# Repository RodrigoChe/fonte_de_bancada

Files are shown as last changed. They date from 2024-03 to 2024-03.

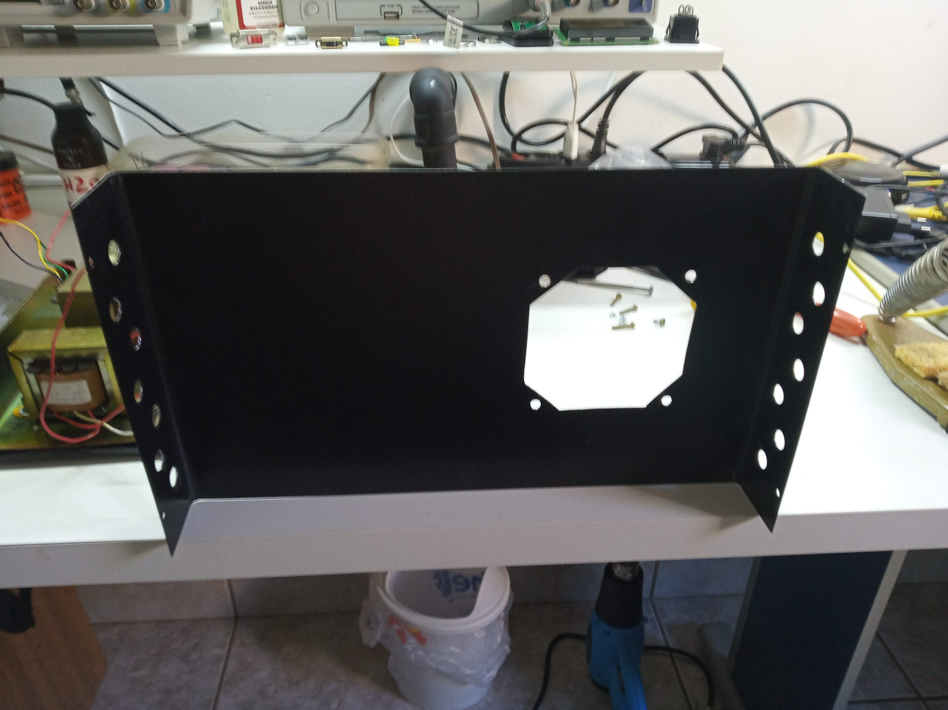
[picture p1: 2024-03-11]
prints_fotos_videos/IMG_20231228_160410.jpg

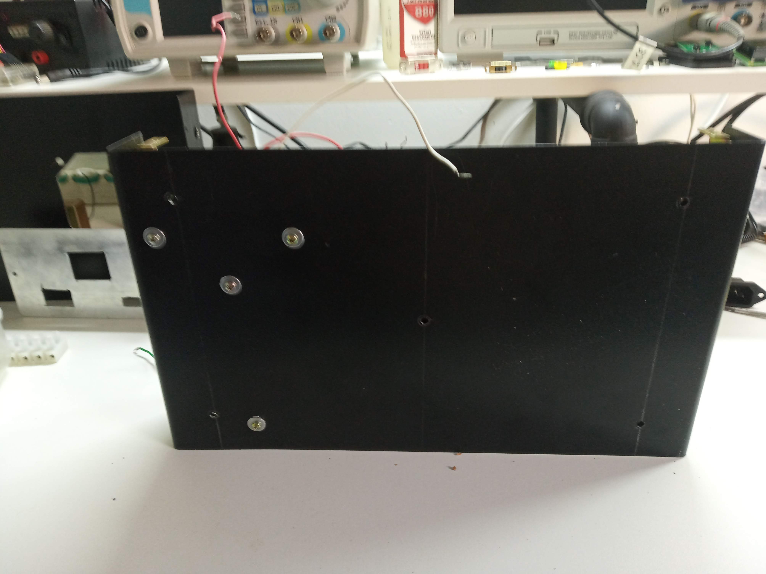
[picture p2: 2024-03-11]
prints_fotos_videos/IMG_20231228_160339.jpg

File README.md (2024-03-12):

# Fonte de bancada 
## Projeto de fonte de bancada ajustável de 1,2V até 30V com corrente de carga contínua de 2A e fonte fixa de 12V com corrente de carga de até 1A.

## Introdução
Este projeto de fonte de bancada handmade tem o objetivo de ser uma opção de baixo custo e boa qualidade para bancada de hobbystas em eletrônica. Foi insparado no projeto de fonte de bancada presente na Revista Mecatrônica Fácil nº 20 de Janeiro/Fevereiro de 2005, com o nome "Fonte para bancada FMF-2" de autoria de Marcio José Soares o Arne, seu projeto original pode ser encontrado [aqui](https://www.arnerobotics.com.br/eletronica/Fonte_bancada_2.htm).
Para o desenvolvimento desse projeto hobbysta foram utilizados:
- Proteus 8.9
- SolidWorks 2019
- Altium 20.0.13
- MikroC 7.2.0

Todas os softwares utilizados com verões trial que possuem limitações de tamanho de placas, número de layers, tamanho de código etc.
Por razões de nostalgia todas as placas foram confecionadas com métodos manuais.
Devido a essas motivações as placas possuem apenas face simples.
A opção por valores de compoenetes e/ou uso de determinado dispisitivo se deve única e exclusivamente a razão de ser  o que havia disponível no momento, a maioria do que foi usado ou já existia na bancada ou foi retirado de eletrônicos velhos. Sinta-se a vontade para modificar quaisqer que sejam os dispositivos e técncias aplicadas. 

## Histórico

Quando era estudante, acho que o ano era 2007, precisava de uma fonte de bancada de baixo ruído para poder realizar meus experimentos com eletrônica e microcontroladores. Foi então que tive acesso a esse artigo da revista Mecatrônica fácil. Na internet na época não tinha encontrado projetos simples que atendessem minha demanda e o baixo conhecimento do idioma inglês dificultava ainda mais rs. 
Dito isso, montei  primeira a versão usando uma carcaça de fonte ATX e alguns componentes que já estavam naquela fonte queimada que encotrei num cemitério de eletrônicos, como conector de rede AC, chave H-H, e mais uns cacarecos. Usei essa montagem por alguns anos até que me mudei de cidade e a fonte ficou abandonada na minha casa antiga. 
Em 2018 resolvi retomar e dar um tapa na minha velha companheira, refiz os esquemáticos e layout e na prensa térmica refiz a placa. Nessa época, aproveitei e já mandei bala em uma fonte fixa de +12 -12 para usar em circuitos com ampOps.
Fiz mais uma mudança e organizando minhas coisas encontrei display de LDC 16x2 que tinha tirado de equipamentos velhos que foram dispensados no meu trabalho e também um PIC18F1220 de saudosos 8 bits que usava para estudar. Como tinha alguns LM358 e um sensor ACS712 que usei para testar umas coisas e depois ficou parado, resolvi fazer um circuito de monitor, porque não neh?
Nessa altura já estavamos mais ou menos na época da pandemia e em meu horário livre aprovetei pra fazer um curso de Altium online e usei o circuito de monitor como objeto de estudo, ao invés do proposto no curso. 
Ai então, a pandemia acabou, voltamos ao normal e minha fonte ainda estava lá parada e desmontada porque não tava rolando uma brecha pra poder mexer. Quando a brecha surgiu optei pela nostalgia em fazer tudo com minhas proprias mãos literalmente. Bem, não tão literal, para prensar a placa do monitor usei um velho ferro de passar roupa e para usinar a caixa usei uma micro retifica de mão (essa altura eu já possuia uma).
E assim foi, montagem, testes, mais uns ajutes ténicos não planejados rs e voalá.

## Conteúdo do repositório

- Cad_mecanico: neste diretório encontram-se arquivos CAD de partes, montagem e pdf's com as medidas.
- prints_fotos_videos: este diretório contém material gráfico do processo de confecção montagem e etc.
- monitor_fonte: arquivos Altium do circuito monitor de corrente, tensão, temperatura e potência, arquivos Proteus de simulação desse circuito, arquivo MikroC de firmware.
- fontes: pdf's dos circuitos esquemáticos das fontes variável e fixa, o arquivo fonte do projeto em Proteus sumiu entre backup's e mudanças. Quando for localizado subo no repositório.

```shell
.
├── cad_mecanico
│   ├── COMPONENTES
│   │   ├── 10A 250VAC Fuse Holder.SLDASM
│   │   ├── 16x2 LCD Display.SLDPRT
│   │   ├── 80 FanCooler-A.SLDASM
│   │   ├── 80 FanCooler-Fan.sldprt
│   │   ├── 80 FanCooler-Frame.sldprt
│   │   ├── 80FanCooler-Guard.sldprt
│   │   ├── Banana Connector - 4.00mm - Short - Black.SLDPRT
│   │   ├── Banana Connector - 4.00mm - Short - Blue.SLDPRT
│   │   ├── Banana Connector - 4.00mm - Short - Green.SLDPRT
│   │   ├── Banana Connector - 4.00mm - Short - Red.SLDPRT
│   │   ├── Banana Connector - 4.00mm - Short - Yellow.SLDPRT
│   │   ├── Chave HH.SLDPRT
│   │   ├── DIN EN ISO 10511 - M4 - N.sldprt
│   │   ├── DIN EN ISO 7045 - M4 x 35 - Z - 35N.sldprt
│   │   ├── EC11_rotary_encoder_knob.SLDPRT
│   │   ├── Frontal.SLDPRT
│   │   ├── Knob 05 v3.SLDASM
│   │   ├── led holder.SLDPRT
│   │   ├── LED_THT_3D_GREEN.SLDPRT
│   │   ├── LED_THT_3D_RED.SLDPRT
│   │   ├── LED_THT_3D_YELLOW.SLDPRT
│   │   ├── Orelha.SLDPRT
│   │   ├── placa_F_fix.SLDPRT
│   │   ├── placa_F_var.SLDPRT
│   │   ├── reforco Interno.SLDPRT
│   │   ├── sapata.SLDPRT
│   │   ├── Switch.SLDPRT
│   │   ├── Tampa.SLDPRT
│   │   ├── TOMADA FÊMEA.SLDPRT
│   │   ├── trafo 1A.SLDPRT
│   │   └── trafo 3A.SLDPRT
│   ├── DESENHOS
│   │   ├── FONTE_montada_1 - Folha1.pdf
│   │   ├── tampa_frontal_1 - Folha1.pdf
│   │   ├── tampa_frontal_2 - Folha1.pdf
│   │   ├── tampa_inferior - Folha1.pdf
│   │   ├── tampa_superior - Folha1.pdf
│   │   ├── tampa_traseira_1 - Folha1.pdf
│   │   └── tampa_traseira_2 - Folha1.pdf
│   └── MONTAGEM
│       └── FONTE.SLDASM
├── fontes
│   ├── esquematicos_placas
│   │   ├── fonte_simetrica_esquema.pdsprj.pdf
│   │   ├── fonte_simetrica.pdsprj.pdf
│   │   ├── fonte_variavel_esquema.pdsprj.pdf
│   │   └── fonte_variavel.pdsprj.pdf
│   └── simulacao_fontes
│       └── Fonte_V1.pdsprj
├── LICENSE
├── monitor_fonte
│   ├── Firmware
│   │   ├── Device.asm
│   │   ├── Device.c
│   │   ├── Device.c.ini
│   │   ├── Device.cp
│   │   ├── Device.h
│   │   ├── Device.h.ini
│   │   ├── Device.mcl
│   │   ├── firmware_monitor.asm
│   │   ├── firmware_monitor.bmk
│   │   ├── firmware_monitor.brk
│   │   ├── firmware_monitor.c
│   │   ├── firmware_monitor.cfg
│   │   ├── firmware_monitor.c.ini
│   │   ├── firmware_monitor.cof
│   │   ├── firmware_monitor.cp
│   │   ├── firmware_monitor.dbg
│   │   ├── firmware_monitor.dct
│   │   ├── firmware_monitor.dlt
│   │   ├── firmware_monitor.hex
│   │   ├── firmware_monitor.log
│   │   ├── firmware_monitor.lst
│   │   ├── firmware_monitor.lst.ini
│   │   ├── firmware_monitor.mcl
│   │   ├── firmware_monitor.mcppi
│   │   ├── firmware_monitor.mcppi_callertable.txt
│   │   ├── firmware_monitor.user.dic
│   │   └── firmware_monitor.wch
│   ├── PCB_Altium
│   │   └── PCB_INSTRUMENTATION_VSOURCE
│   │       ├── main.SchDoc
│   │       ├── PCB_INST_FONTE.PcbDoc
│   │       ├── PCB_INSTRUMENTATION_VSOURCE.PrjPcb
│   │       ├── __Previews
│   │       │   ├── main.SchDocPreview
│   │       │   ├── Sheet1.SchDocPreview
│   │       │   └── Sheet2.SchDocPreview
│   │       ├── Producao
│   │       │   ├── Geber_Placa.Cam
│   │       │   ├── NC_Drill_Placa.Cam
│   │       │   ├── Schematic Prints 1.pdf
│   │       │   ├── Schematic Prints 2.pdf
│   │       │   ├── Schematic Prints.pdf
│   │       │   └── Thermal_transfer
│   │       │       ├── Mask_Impressao_TermoCAM.pdf
│   │       │       ├── Mask_Print_Term_Transfer.pdf
│   │       │       └── Print_Fab_Home_Thermal.pdf
│   │       ├── Project Outputs for PCB_INSTRUMENTATION_VSOURCE
│   │       │   ├── Design Rule Check - PCB_INST_FONTE.drc
│   │       │   ├── Design Rule Check - PCB_INST_FONTE.html
│   │       │   ├── PCB_INST_FONTE.apr
│   │       │   ├── PCB_INST_FONTE.DRR
│   │       │   ├── PCB_INST_FONTE.EXTREP
│   │       │   ├── PCB_INST_FONTE.GBL
│   │       │   ├── PCB_INST_FONTE.GBO
│   │       │   ├── PCB_INST_FONTE.GBS
│   │       │   ├── PCB_INST_FONTE.GG1
│   │       │   ├── PCB_INST_FONTE.GM1
│   │       │   ├── PCB_INST_FONTE.GM13
│   │       │   ├── PCB_INST_FONTE.GM15
│   │       │   ├── PCB_INST_FONTE.GPB
│   │       │   ├── PCB_INST_FONTE.GPT
│   │       │   ├── PCB_INST_FONTE.GTL
│   │       │   ├── PCB_INST_FONTE.GTO
│   │       │   ├── PCB_INST_FONTE.GTS
│   │       │   ├── PCB_INST_FONTE.LDP
│   │       │   ├── PCB_INST_FONTE-macro.APR_LIB
│   │       │   ├── PCB_INST_FONTE.REP
│   │       │   ├── PCB_INST_FONTE.RUL
│   │       │   ├── PCB_INST_FONTE.TXT
│   │       │   ├── PCB_INSTRUMENTATION_VSOURCE_BOM.xlsx
│   │       │   ├── __Previews
│   │       │   │   └── Design Rule Check - PCB_INST_FONTE.drcPreview
│   │       │   └── Status Report.Txt
│   │       ├── Sheet1.SchDoc
│   │       └── Sheet2.SchDoc
│   └── Simulacao
│       └── simulacao_monitor_fonte.pdsprj
├── prints_fotos_videos
│   ├── cad_vista_monategm_1.png
│   ├── cad_vista_monategm_2.png
│   ├── cad_vista_monategm_3.png
│   ├── cad_vista_monategm_4.png
│   ├── IMG-20220224-WA0000.jpg
│   ├── IMG-20220224-WA0002.jpg
│   ├── IMG-20220224-WA0003.jpg
│   ├── IMG-20220224-WA0004.jpg
│   ├── IMG_20220310_143831.jpg
│   ├── IMG_20220310_143843.jpg
│   ├── IMG_20220315_130520.jpg
│   ├── IMG_20220315_130540.jpg
│   ├── IMG_20220921_200834.jpg
│   ├── IMG_20220921_201358.jpg
│   ├── IMG-20230129-WA0006.jpeg
│   ├── IMG_20231120_121806.jpg
│   ├── IMG_20231228_160329.jpg
│   ├── IMG_20231228_160339.jpg
│   ├── IMG_20231228_160359.jpg
│   ├── IMG_20231228_160410.jpg
│   ├── IMG_20231229_150956.jpg
│   ├── IMG_20240110_225814.jpg
│   ├── IMG_20240113_172508.jpg
│   ├── IMG_20240113_201511.jpg
│   ├── IMG_20240210_154214.jpg
│   ├── IMG-20240229-WA0002.jpeg
│   ├── IMG-20240301-WA0006.jpeg
│   ├── IMG-20240301-WA0008.jpeg
│   ├── IMG-20240301-WA0012.jpeg
│   ├── simula.PNG
│   └── VID-20240301-WA0018.mp4
└── README.md
```

## Observações

Circuito de fonte simétrica fixa.
Este circuito é extremamente simples sendo composto por um retificador em ponte completa com trasnformador de 15+15 @1A, diodos 1N4004, filtro capacitivo e reguladores LM7812 e LM7912. Seu layout pode ser bastante reduzido, sugiro colocar bons dissipadores de calor (reguladores lineares dissipam muito calor). Os leds de sinalização são totalmente dispensáveis, caso opte por eles seria interessante um trafo maior para termos um pouco mais de 15V na entrada do regulador, pois a tensão dropOut necessária para regulação fica em torno de uns 3V. 

Circuito de fonte ajustável.
Este circuito também é simples sendo composto por um transformador abaixador de 15+15V @3A, ponte retificadora com 4 diodos 1N5408, filtro capacitivo e regulador LM350. O layout que usei foi inspirado no da revista, mas o LM350 sugiro monta-lo separado com um dissipador de calor grande para poder fornecer os 3A sem acionar o circuito de proteção térmica. Com isso o layout fica bem reduzido também.  Outa sugestão é utilizar outro encapsulamento e colocar os diodos de proteção conforme o datasheet do componente encontrado [aqui](https://www.ti.com/lit/ds/symlink/lm350-n.pdf?ts=1710238548220&ref_url=https%253A%252F%252Fwww.mouser.fr%252F). No esquemático deste projeto utilizei o capacitor de redução de ripple, conforme o datasheet isso tende a melhorar a resposta para ruídos de entrada sob carga. 

Circuito monitor
Bem este circuito já não é tão simples, pois possui um mirocontrolador PIC18F1220 que precisa de um firmware para funcionar. Sua finalidade é medir a tensão, corrente, temperatura, potência de saída da fonte ajustável e medir se a tensão fixa esta dentro de limites aceitáveis (tinha espaço no LCD). Apresentando a medida em um display de LCD 16x2 vias. 
Para medir tensão são usados divisores de tensão na entreda de LM358's datasheet [aqui](https://www.ti.com/lit/ds/symlink/lm358.pdf?ts=1710219620944) como buffers de tensão que servem pra isolar e proteger o microcontrolador, também foram usados diodo zener de proteção e um filtro RC. Para a medição de tempratura foi usado o famigerado LM35  [datasheet](https://www.ti.com/lit/ds/symlink/lm35.pdf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), foi fixado perto do LM350 no dissipador de calor usando adesivo térmico homemade vulgo pasta térmica com adesivo epóxi. Para medição de corrente foi usado um módulo do sensor ACS712 datasheet [aqui](https://www.sparkfun.com/datasheets/BreakoutBoards/0712.pdf), esse dispositivo apenas foi usado porque tinha disponível. Ele é bem ruim para baixas correntes dc. Ficando mais como um alarme do que uma medida confiável. Sugiro a substituição desse sensor ou mesmo projetar algo com compnentes discretos. 
Para o firmware do microcontrolador quiz usar o ambiente que usava [Na aurora da minha vida!](https://poemasdomundo.wordpress.com/2006/06/14/meus-oito-anos/) lá no tempo do curso técnico (o Arduino não era muito conhecido ainda...). Então foi na base do MikroC mesmo que tem umas libs que facilitam trabalhar com display. Hoje em dia compensa muito mais usar as ferramentas da Microchip, Mplab, Harmony e etc. 
Por último, sugiro usar um circuitinho de referência externa de tensão para o ADC, mesmo em outros microocntroladores. Neste projeto foi usado o TL431 datasheet [aqui](https://www.ti.com/lit/ds/symlink/tl431.pdf?ts=1710220283391&ref_url=https%253A%252F%252Fwww.mouser.com%252F).
Sinceramente, da pra dispensar esse circuito com traqnuilidade, caso queira economizar dinheiro e mão de obra pode optar por um monitor pronto com voltimetro e amperimetro Dc (desses que vende barato em sites amarelos da rede mundial de computadores) [como exemplo](https://www.4hobby.com.br/produto/voltimetro-amperimetro-digital-dc-100v-10a-para-painel.html).

Montagem
Para montagem foi utilizado uma caixa metálica de  300x180x80 mm tem algumas opções na internet por [ai](https://www.soldafria.com.br/componentes-eletronicos/caixa/caixa-de-ferro) (de longe a caixa foi o componente mais caro). Outra opção pode ser caixas padrão plásticas, reaproveitar alguma coisa, fazer de madeira, opções existem e a imaginação é o limite. Recomendo fortemente o uso de ventilação forçada a famosa ventoinha e o uso de bons bornes e chaves de qualidade.
Um vídeo da fonte alimentando uam lampada DC e um circuito amplificador pode ser visto [neste link](https://www.youtube.com/shorts/OysOYpLijRs).

## License

MIT

**Free Software, Hell Yeah!**

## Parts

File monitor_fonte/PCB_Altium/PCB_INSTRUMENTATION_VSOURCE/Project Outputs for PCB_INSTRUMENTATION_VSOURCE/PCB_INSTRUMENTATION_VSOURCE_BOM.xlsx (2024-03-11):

Comment | Description | Designator | Footprint | LibRef | Quantity | Supplier 1 | Supplier Part Number 1
100nF | Capacitor | C1, C3, C5, C7, C11 | RAD-0.2 | C | 5
2200 uF @25V | Polarized Capacitor | C2 | CAPPR5-13x21 | CP | 1
330nF | Capacitor | C4, C6 | RAD-0.2 | C | 2
22pF | Capacitor | C8, C9, C10 | RAD-0.2 | C | 3
100n | Capacitor | C12, C13, C14, C15, C16, C17, C18 | RAD-0.2 | C | 7
1N4007 | Diode | D1, D2, D3, D4 | DIODE-1N400X | D | 4
1N4007 | 1 Amp General Purpose Rectifier | D5 | DO-41 | Diode 1N4007 | 1
1N4733 | Zener Diode | D6, D7, D8 | DIODE-SIGNAL | D Zener | 3
AC(IN) | Header, 3-Pin | P1 | HDR1X3 | Header 3 | 1
LCD 16x2 | Header, 10-Pin | P2 | HDR1X10 | Header 10 | 1
FAN | Header, 3-Pin | P3 | HDR1X3 | Header 3 | 1
V var | Header, 3-Pin | P4 | HDR1X3 | Header 3 | 1
V fixed | Header, 3-Pin | P5 | HDR1X3 | Header 3 | 1
ACS712 | Header, 3-Pin | P6 | HDR1X3 | Header 3 | 1
4k7 | Resistor | R1 | AXIAL-0.4 | R | 1
150r | Resistor | R2 | AXIAL-0.4 | R | 1
12k | Resistor | R3, R7 | AXIAL-0.4 | R | 2
24k | Potentiometer | R4 | VR1 | R Pot | 1
6k8 | Resistor | R5 | AXIAL-0.4 | R | 1
100k | Potentiometer | R6 | VR1 | R Pot | 1
100k | Resistor | R8 | AXIAL-0.4 | R | 1
1k | Resistor | R9, R10, R11 | AXIAL-0.4 | R | 3
100 | Resistor | R12 | AXIAL-0.4 | R | 1
PIC18F1220-I/P | High Performance, Enhanced Flash Microcontroller with 10-Bit A/D and nanoWatt Technology, 4K Flash, 18-Pin PDIP, Industrial Temperature | U1 | PDIP300-P18 | PIC18F1220-I/P | 1 | Digi-Key | PIC18F1220-I/P-ND
LM7812 | Series 3-Terminal Positive Regulators, 3-pin TO-220 | U2 | T03B | LM7808CT | 1 | Farnell | 9490248
LM7805 | Series 3-Terminal Positive Regulators, 3-pin TO-220 | U3 | T03B | LM7808CT | 1 | Farnell | 9490248
TL431ACLP | Adjustable Precision Shunt Regulator | U4 | LP03 | TL431ACLP | 1
LM358AJG | Dual Operational Amplifier | U5, U6 | JG008 | LM358AJG | 2
LM35CAZ | Precision Centigrade Temperature Sensor, 3-pin TO-92 | U7 | Z03A | LM35CAZ | 1 | Farnell | 9494529
10MHz | Crystal Oscillator | Y1 | CRYSTAL-HC49S | XTAL | 1

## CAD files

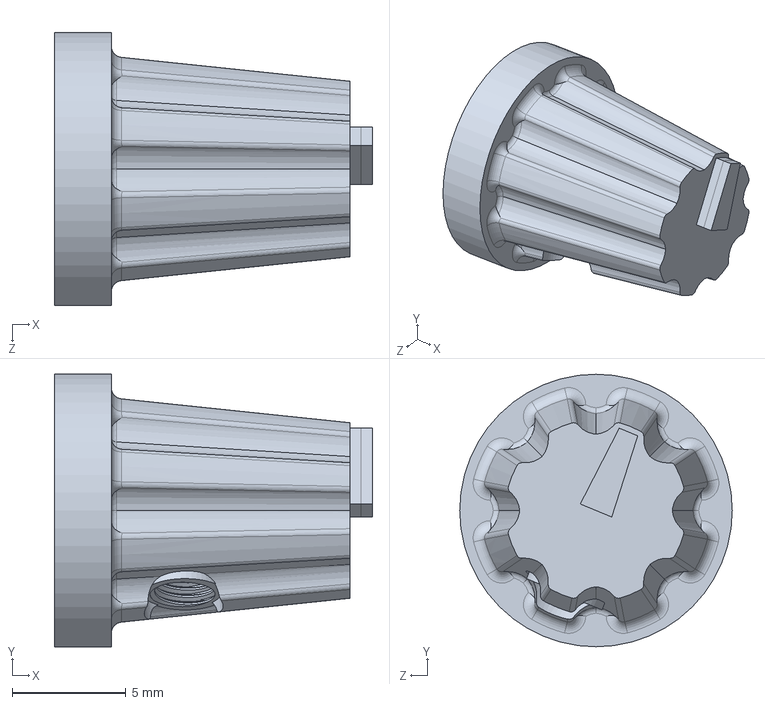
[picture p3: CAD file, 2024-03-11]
cad_mecanico/COMPONENTES/Knob 05 v3.SLDASM
14.0 x 12.0 x 12.0 mm

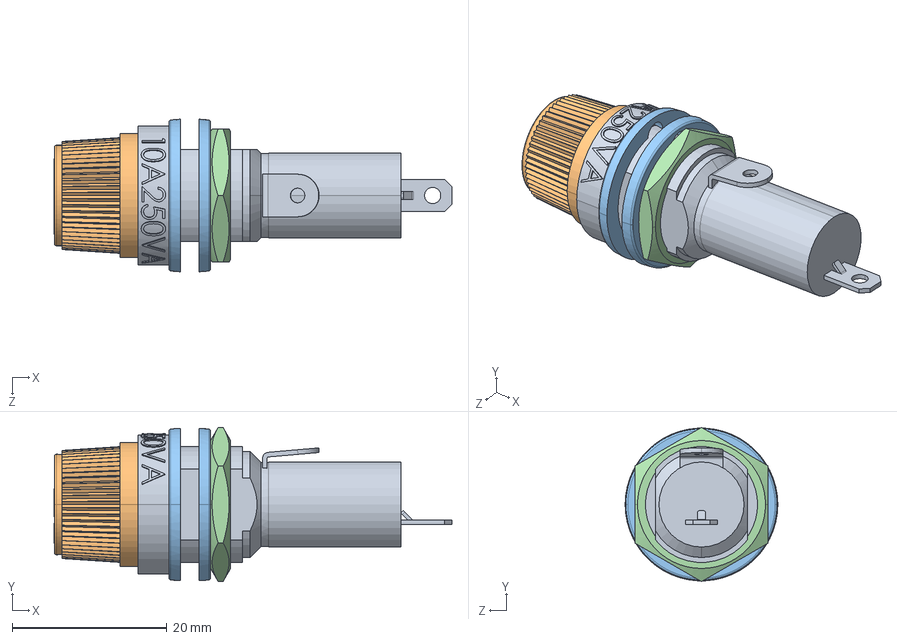
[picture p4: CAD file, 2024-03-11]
cad_mecanico/COMPONENTES/10A 250VAC Fuse Holder.SLDASM
51.5 x 19.9 x 19.8 mm
SF372 - Body.STEP
SF372 - Cap.STEP
SF372 - Nylon Washer.STEP x 2
SF372 - Nut.STEP

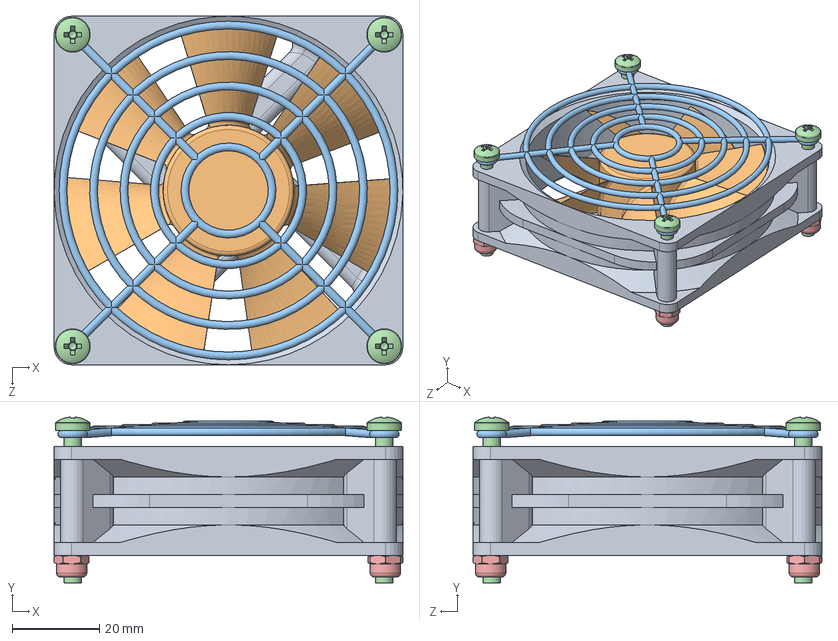
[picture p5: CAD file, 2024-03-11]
cad_mecanico/COMPONENTES/80 FanCooler-A.SLDASM
80.1 x 38.0 x 80.1 mm
80 FanCooler-Frame
80 FanCooler-Fan
80FanCooler-Guard
DIN EN ISO 7045 - M4 x 35 - Z - 35N x 4
DIN EN ISO 10511 - M4 - N x 4

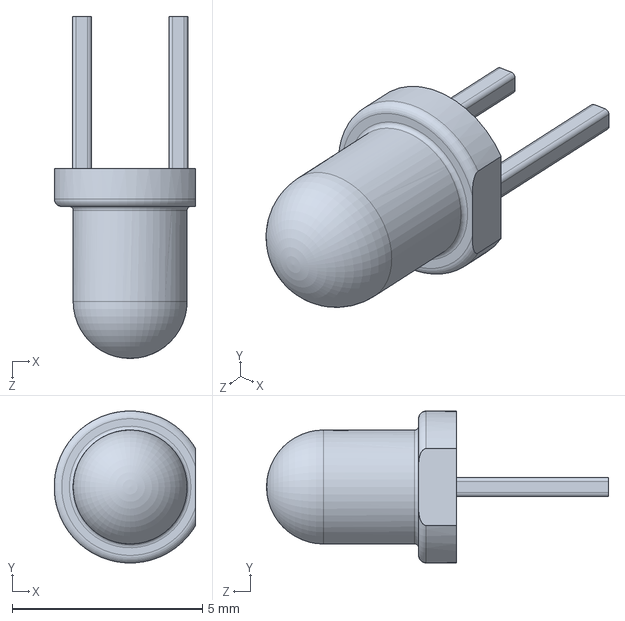
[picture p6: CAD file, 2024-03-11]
cad_mecanico/COMPONENTES/LED_THT_3D_GREEN.SLDPRT
3.72 x 4.00 x 9.00 mm

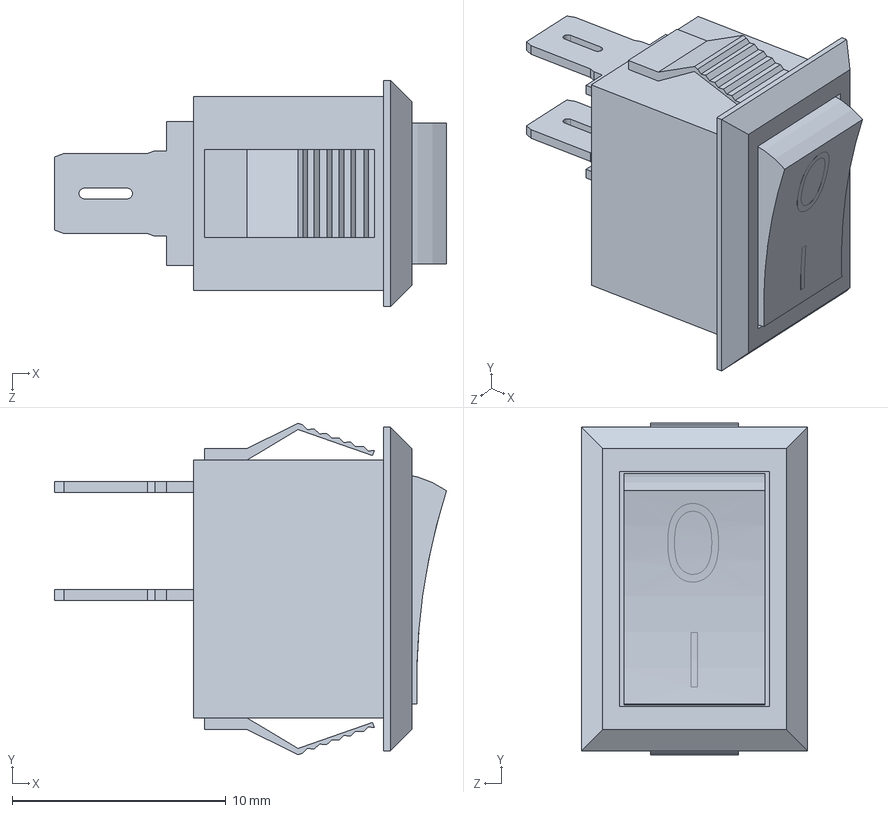
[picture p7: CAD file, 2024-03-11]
cad_mecanico/COMPONENTES/Switch.SLDPRT
18.3 x 15.5 x 10.6 mm

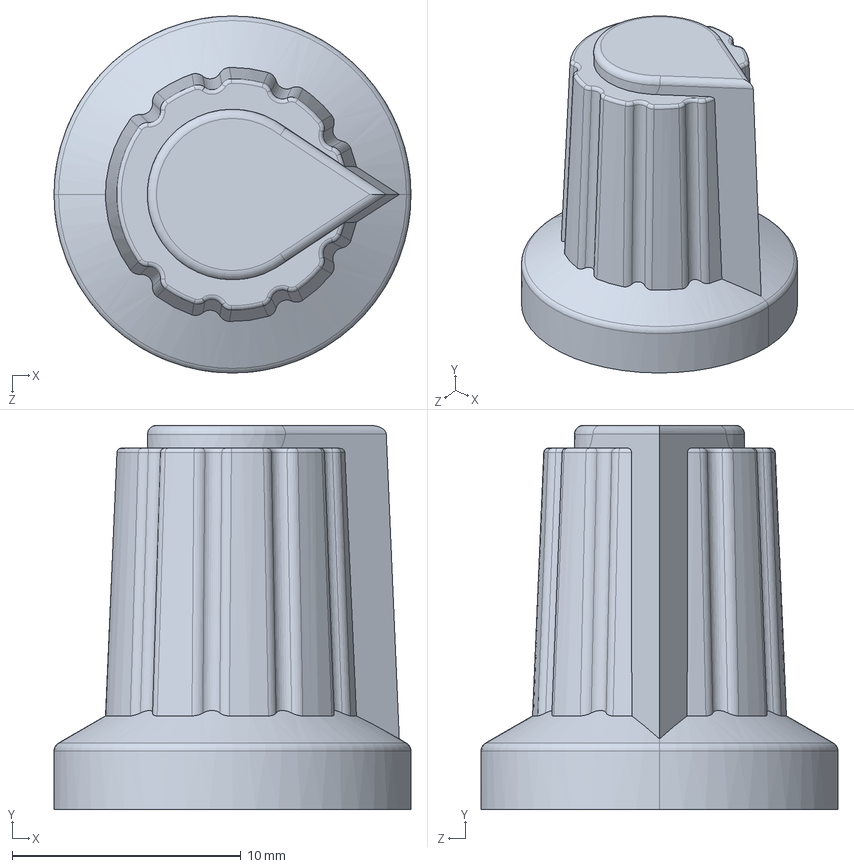
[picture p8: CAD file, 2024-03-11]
cad_mecanico/COMPONENTES/EC11_rotary_encoder_knob.SLDPRT
15.6 x 16.8 x 15.6 mm

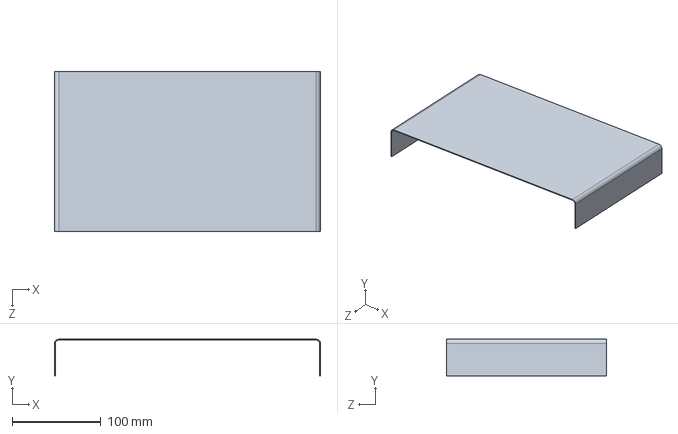
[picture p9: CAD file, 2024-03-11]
cad_mecanico/COMPONENTES/Tampa.SLDPRT
300.0 x 41.3 x 180.0 mm

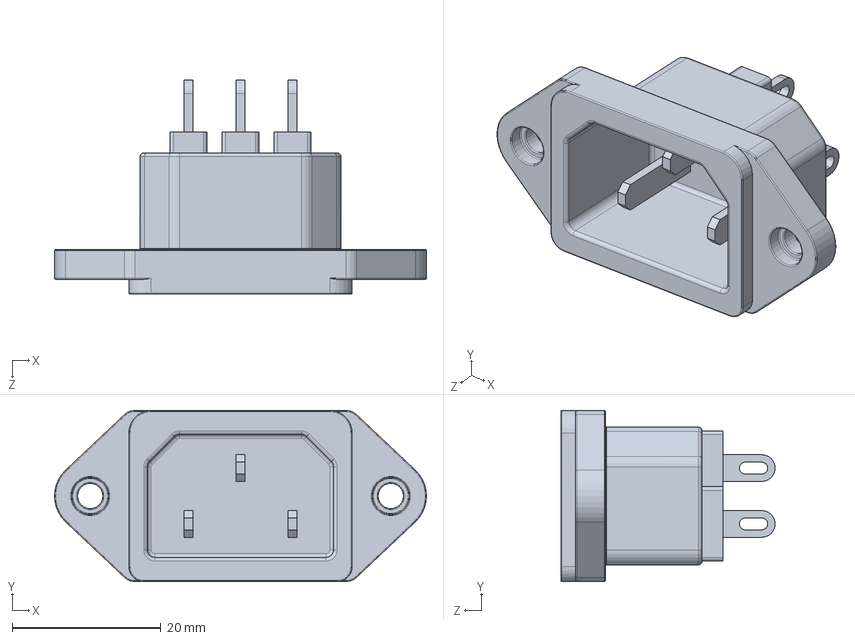
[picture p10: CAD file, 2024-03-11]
cad_mecanico/COMPONENTES/TOMADA FÊMEA.SLDPRT
50.0 x 23.0 x 28.8 mm

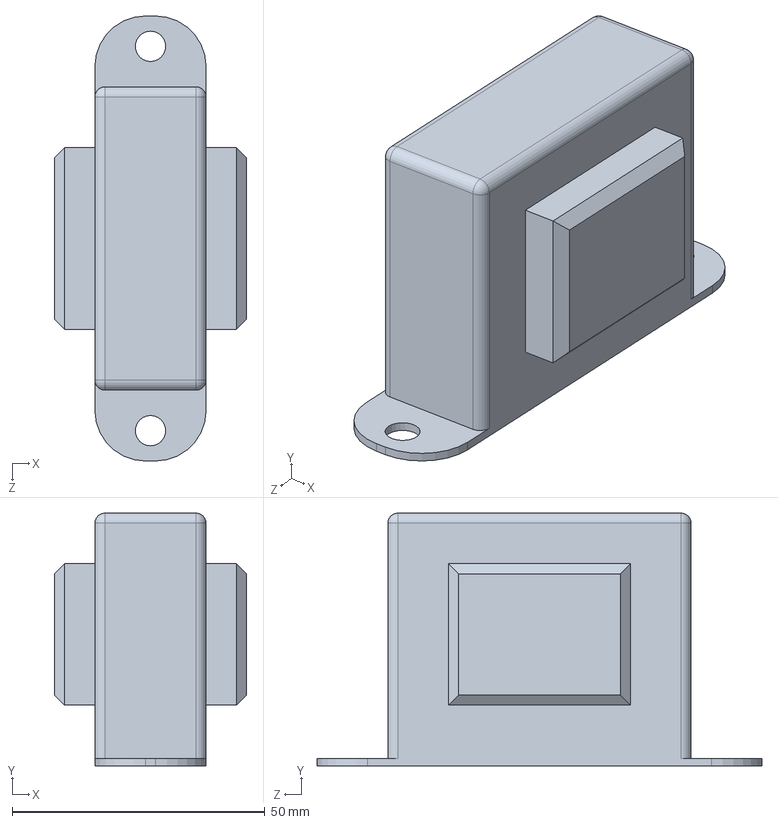
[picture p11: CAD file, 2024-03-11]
cad_mecanico/COMPONENTES/trafo 1A.SLDPRT
38.0 x 50.0 x 88.0 mm

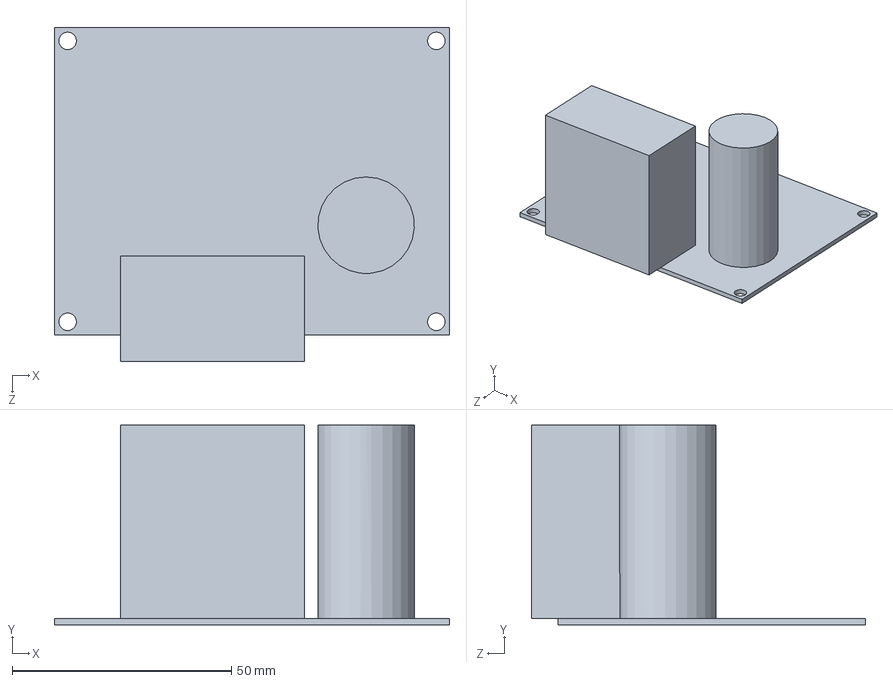
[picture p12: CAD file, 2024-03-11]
cad_mecanico/COMPONENTES/placa_F_var.SLDPRT
90.0 x 45.5 x 76.0 mm

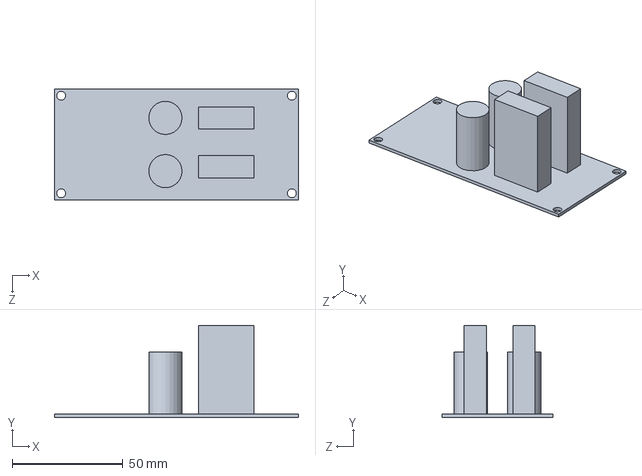
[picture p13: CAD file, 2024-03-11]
cad_mecanico/COMPONENTES/placa_F_fix.SLDPRT
110.0 x 41.5 x 50.0 mm

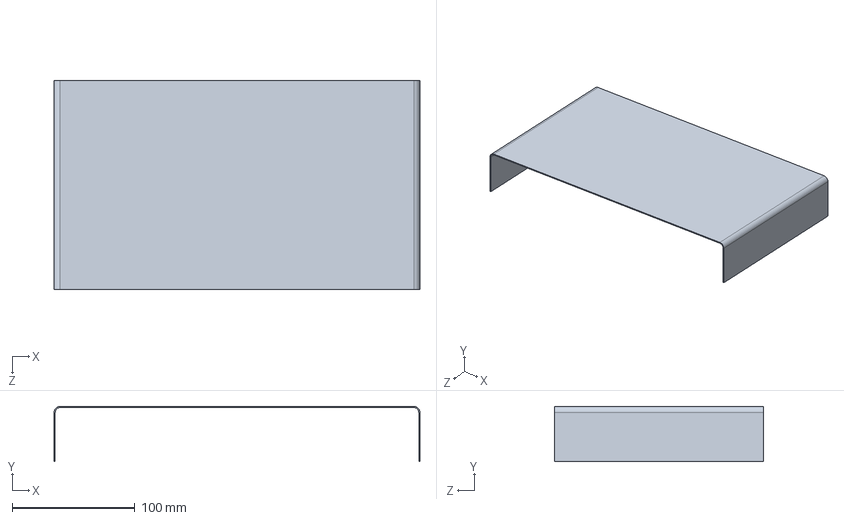
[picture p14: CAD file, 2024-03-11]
cad_mecanico/COMPONENTES/reforco Interno.SLDPRT
298.0 x 45.0 x 170.0 mm

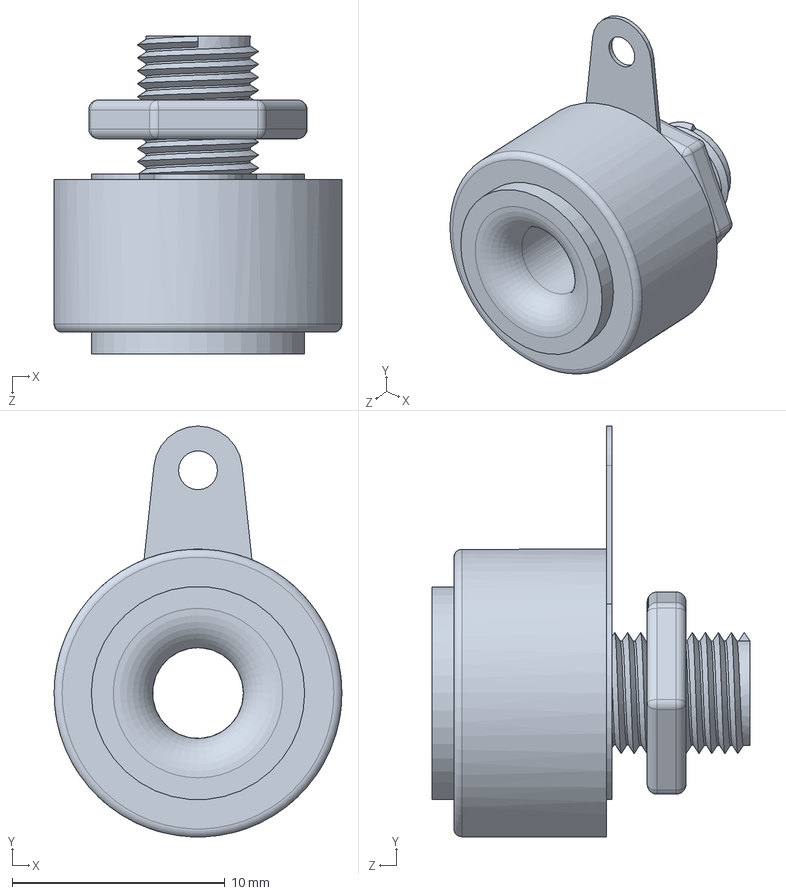
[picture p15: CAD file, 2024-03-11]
cad_mecanico/COMPONENTES/Banana Connector - 4.00mm - Short - Green.SLDPRT
13.5 x 19.3 x 14.9 mm

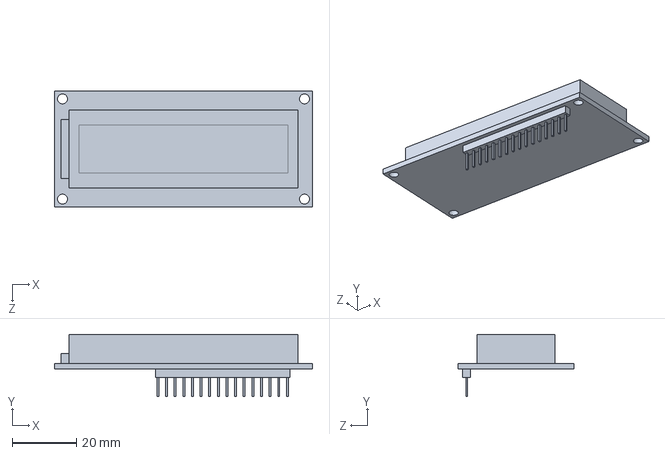
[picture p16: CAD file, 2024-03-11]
cad_mecanico/COMPONENTES/16x2 LCD Display.SLDPRT
80.1 x 19.3 x 36.1 mm

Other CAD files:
cad_mecanico/COMPONENTES/LED_THT_3D_YELLOW.SLDPRT
cad_mecanico/COMPONENTES/Banana Connector - 4.00mm - Short - Yellow.SLDPRT
cad_mecanico/COMPONENTES/Banana Connector - 4.00mm - Short - Blue.SLDPRT
cad_mecanico/COMPONENTES/80 FanCooler-Fan.sldprt
cad_mecanico/COMPONENTES/80 FanCooler-Frame.sldprt
cad_mecanico/COMPONENTES/80FanCooler-Guard.sldprt
cad_mecanico/COMPONENTES/Banana Connector - 4.00mm - Short - Black.SLDPRT
cad_mecanico/COMPONENTES/Banana Connector - 4.00mm - Short - Red.SLDPRT
cad_mecanico/COMPONENTES/Chave HH.SLDPRT
cad_mecanico/COMPONENTES/DIN EN ISO 10511 - M4 - N.sldprt
cad_mecanico/COMPONENTES/DIN EN ISO 7045 - M4 x 35 - Z - 35N.sldprt
cad_mecanico/COMPONENTES/Frontal.SLDPRT
cad_mecanico/COMPONENTES/LED_THT_3D_RED.SLDPRT
cad_mecanico/COMPONENTES/Orelha.SLDPRT
cad_mecanico/COMPONENTES/led holder.SLDPRT
cad_mecanico/COMPONENTES/sapata.SLDPRT
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

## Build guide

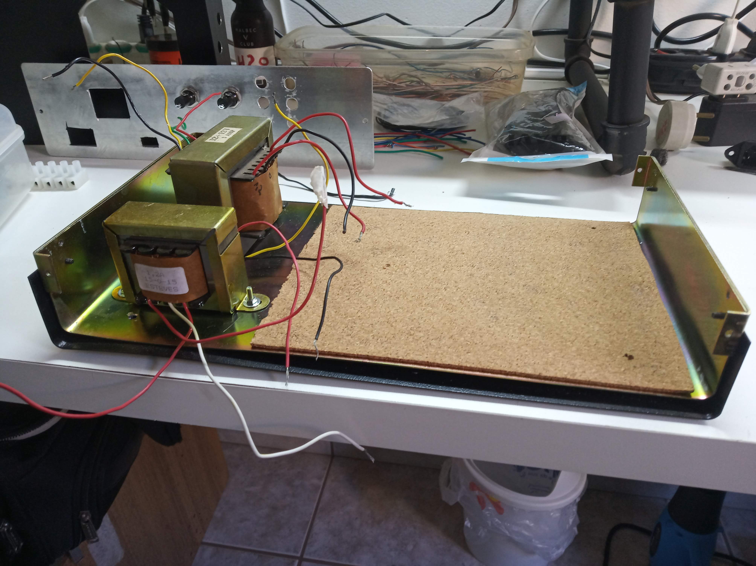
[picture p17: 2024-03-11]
prints_fotos_videos/IMG_20231228_160329.jpg

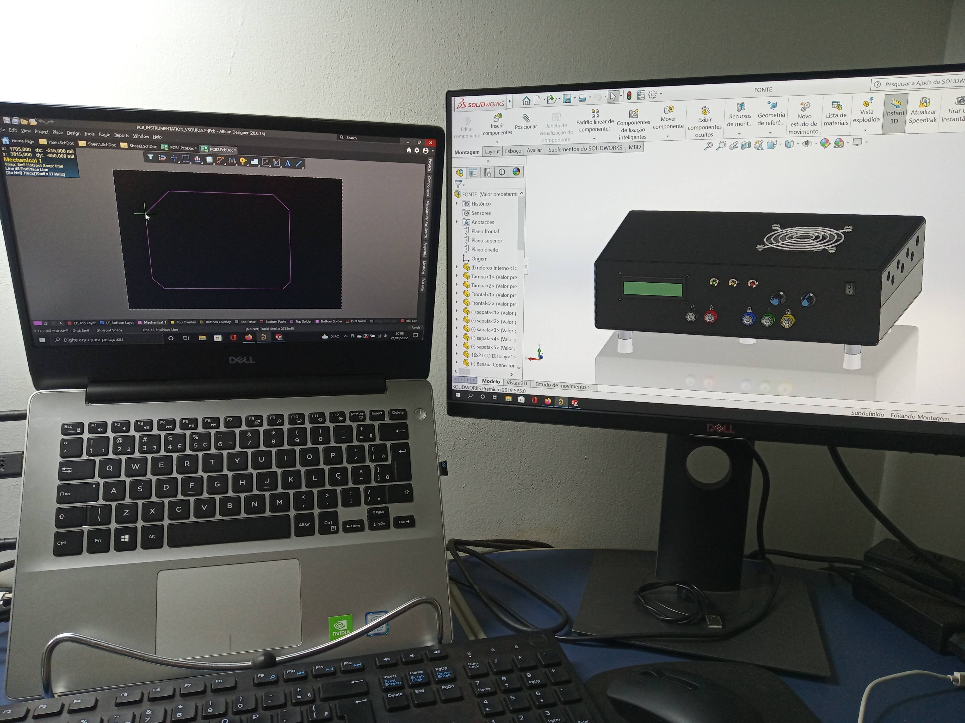
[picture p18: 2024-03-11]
prints_fotos_videos/IMG_20220921_200834.jpg

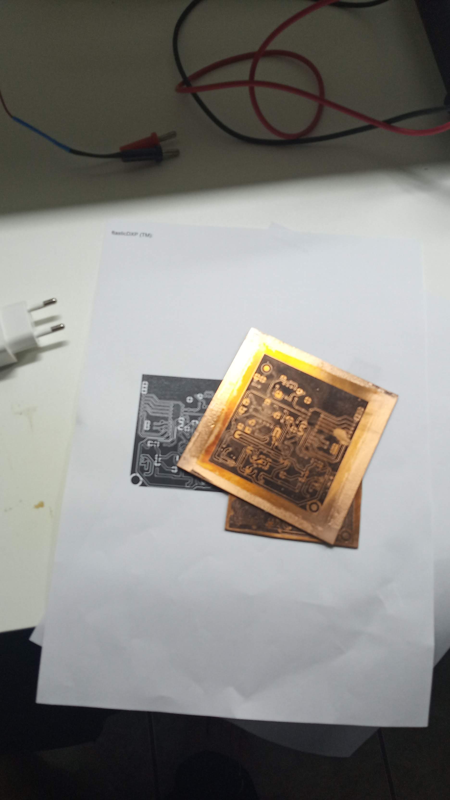
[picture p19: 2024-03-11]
prints_fotos_videos/IMG-20230129-WA0006.jpeg

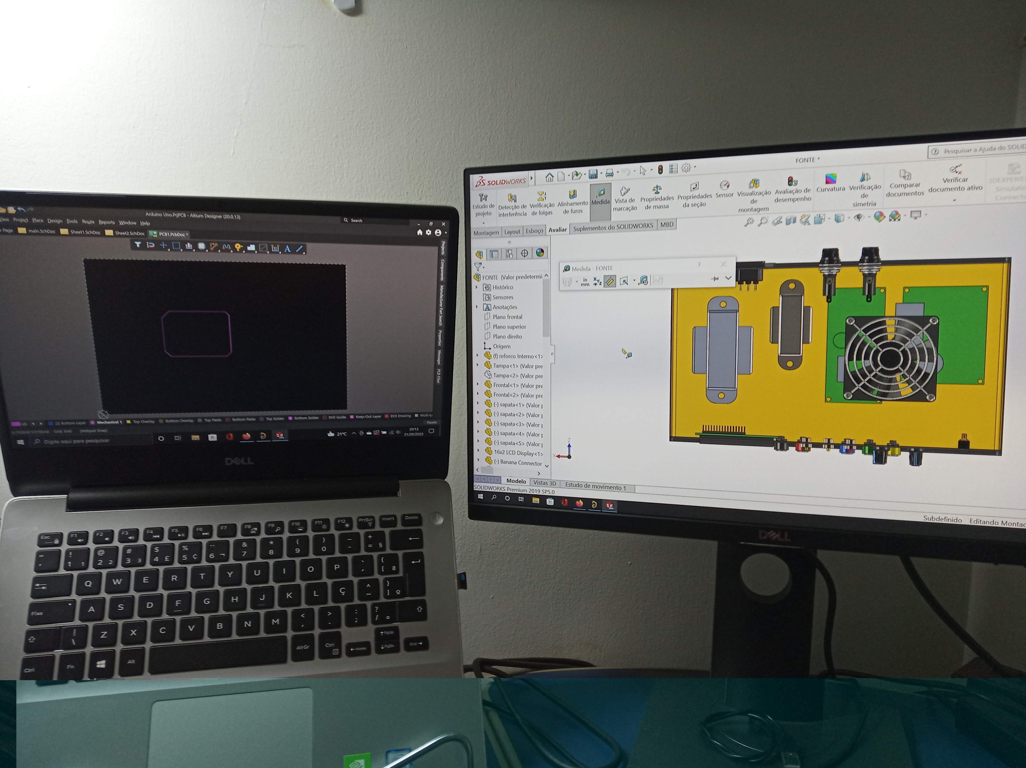
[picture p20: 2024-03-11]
prints_fotos_videos/IMG_20220921_201358.jpg

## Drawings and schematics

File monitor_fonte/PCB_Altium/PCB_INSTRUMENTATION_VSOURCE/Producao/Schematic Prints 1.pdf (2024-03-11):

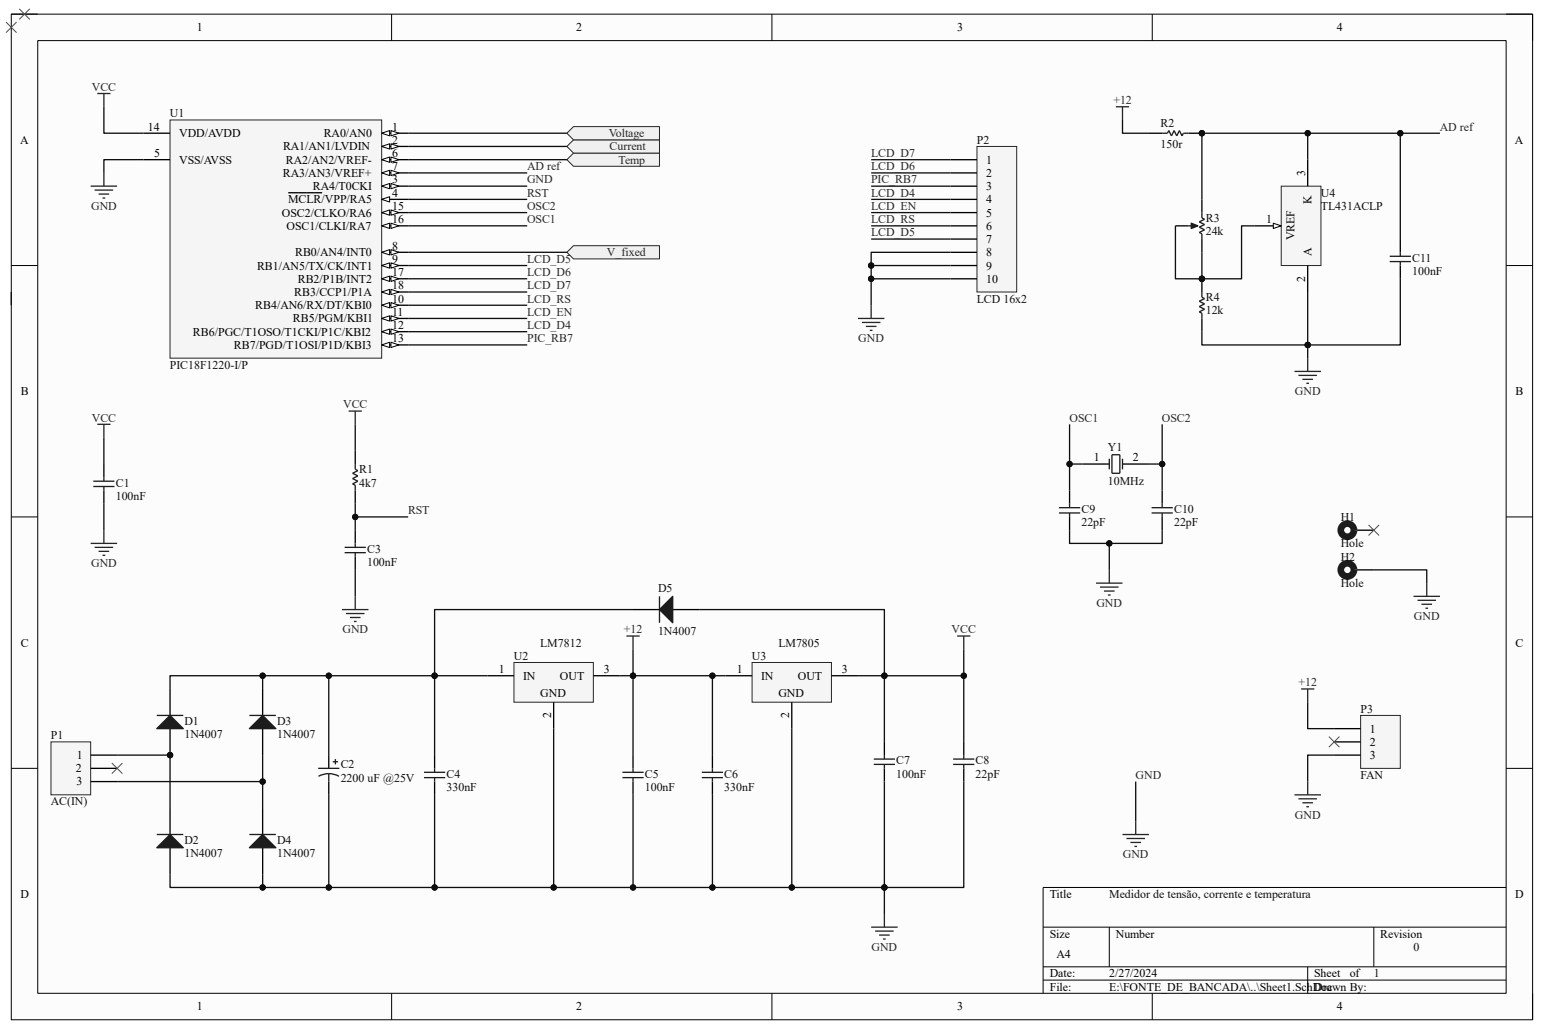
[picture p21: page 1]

Medidor de tensão, corrente e temperatura

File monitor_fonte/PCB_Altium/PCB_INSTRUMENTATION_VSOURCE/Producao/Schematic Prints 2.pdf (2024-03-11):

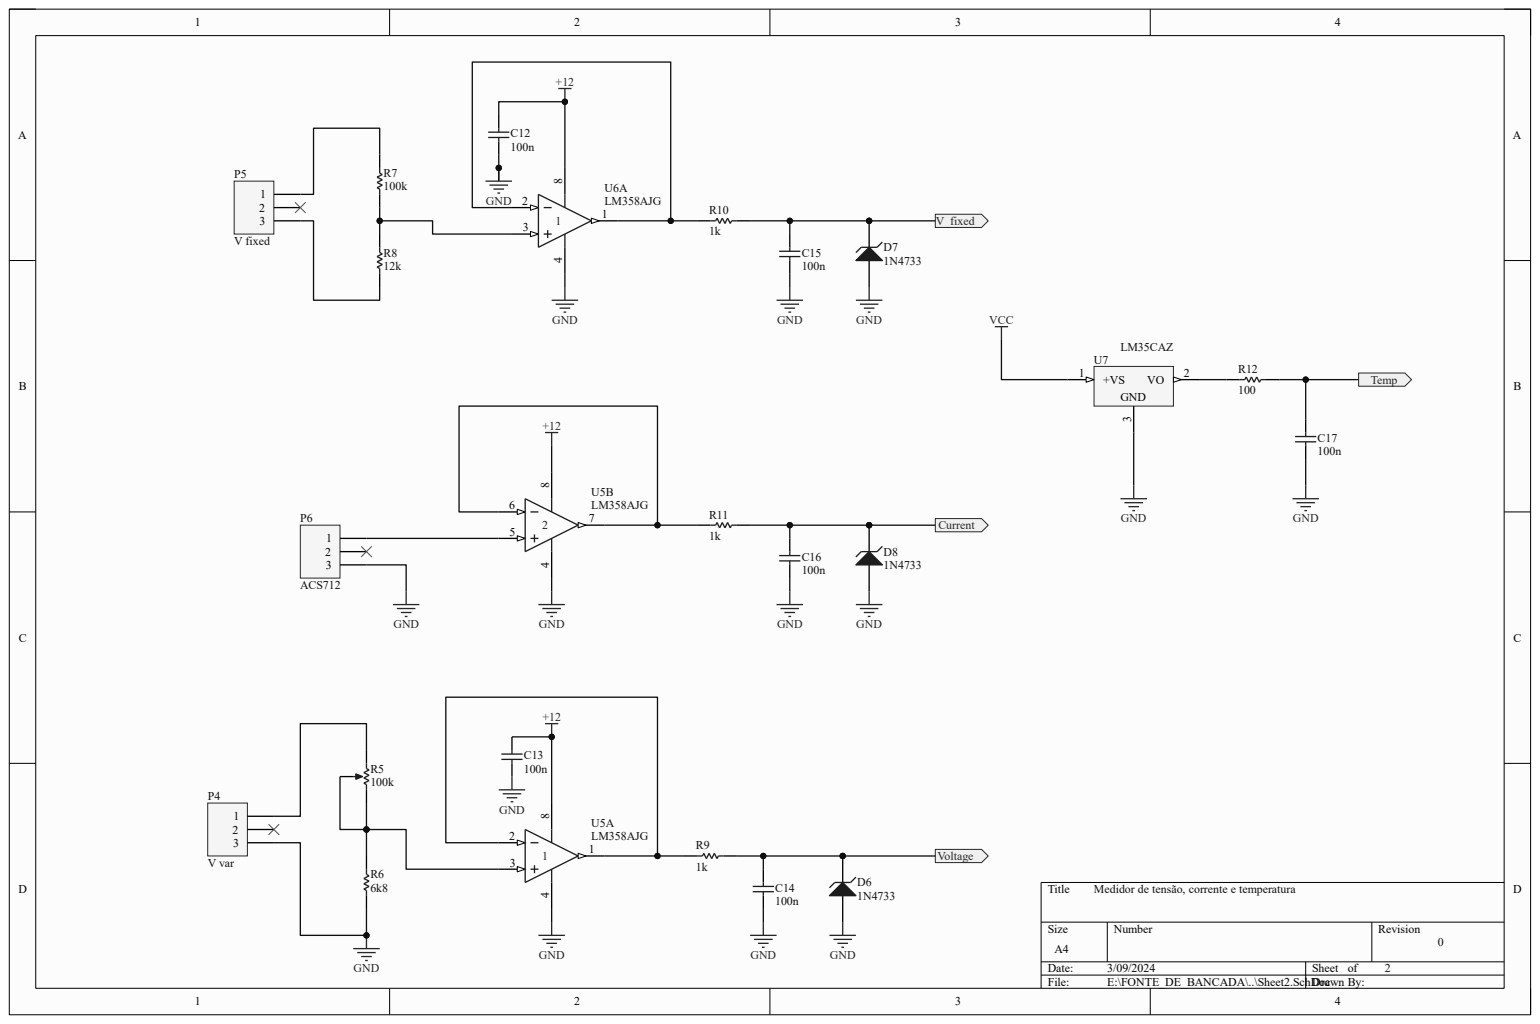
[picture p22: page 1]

Medidor de tensão, corrente e temperatura

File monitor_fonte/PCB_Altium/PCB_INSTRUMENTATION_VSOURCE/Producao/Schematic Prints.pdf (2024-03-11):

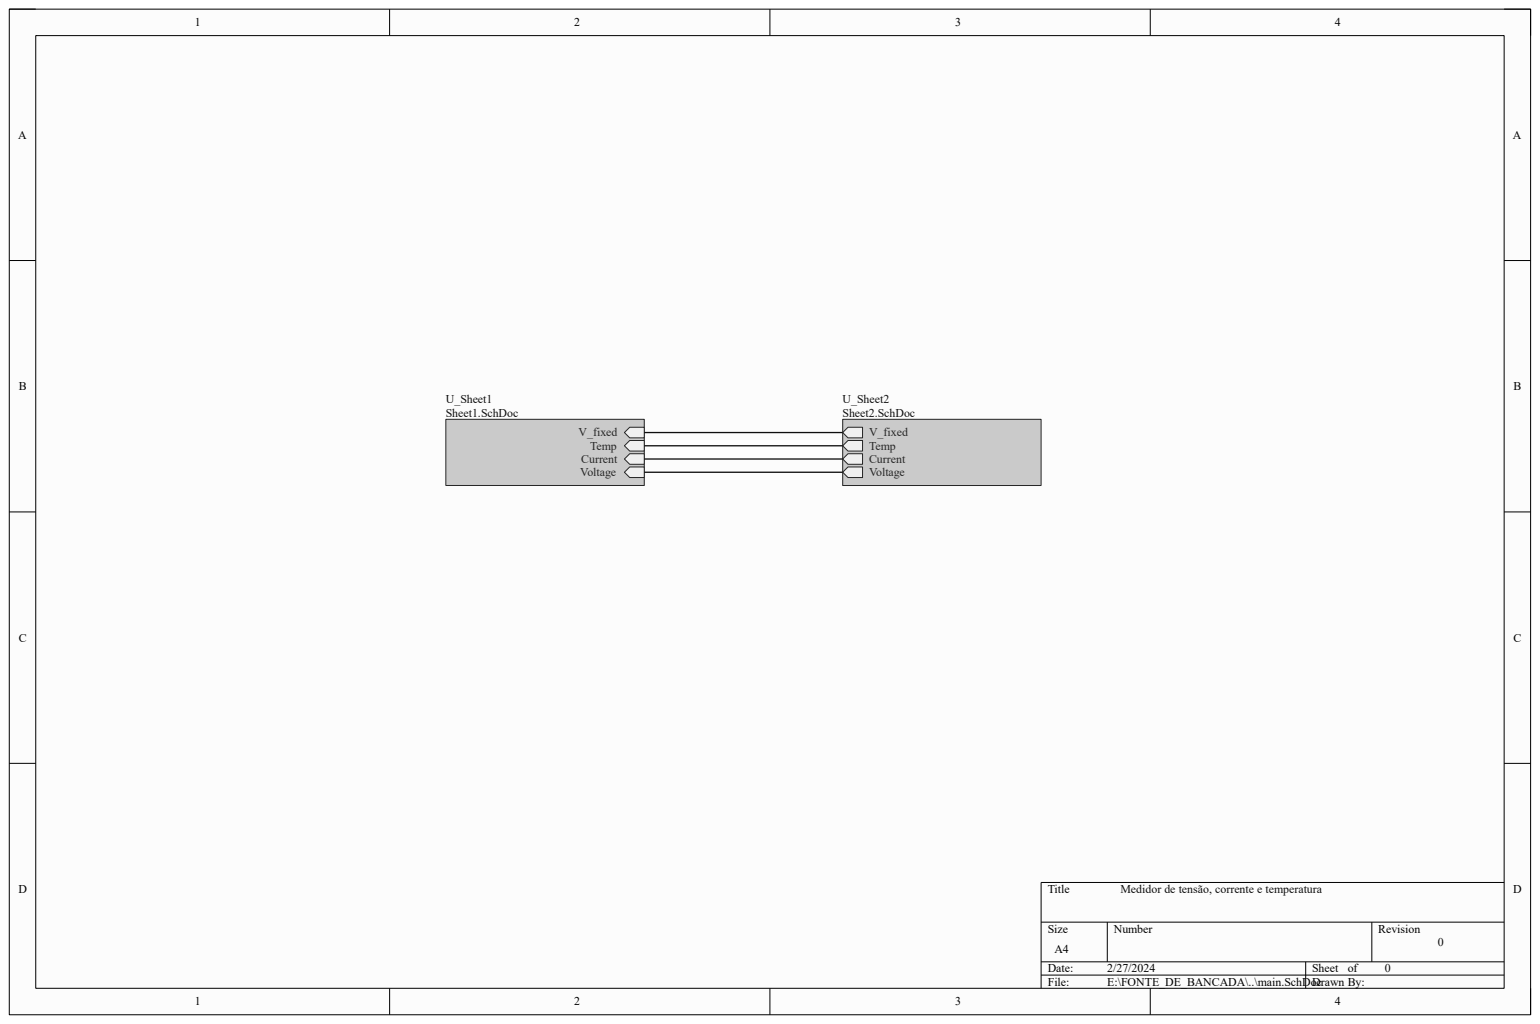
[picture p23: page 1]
Title; Size; Number; Revision; Date:; Sheet of; File:; E:\FONTE_DE_BANCADA\..\main.SchDocDrawn By:; V_fixed Temp Current Voltage; U_Sheet1 Sheet1.SchDoc; U_Sheet2 Sheet2.SchDoc

Medidor de tensão, corrente e temperatura

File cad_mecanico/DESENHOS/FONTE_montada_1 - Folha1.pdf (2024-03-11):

N | N
P | P

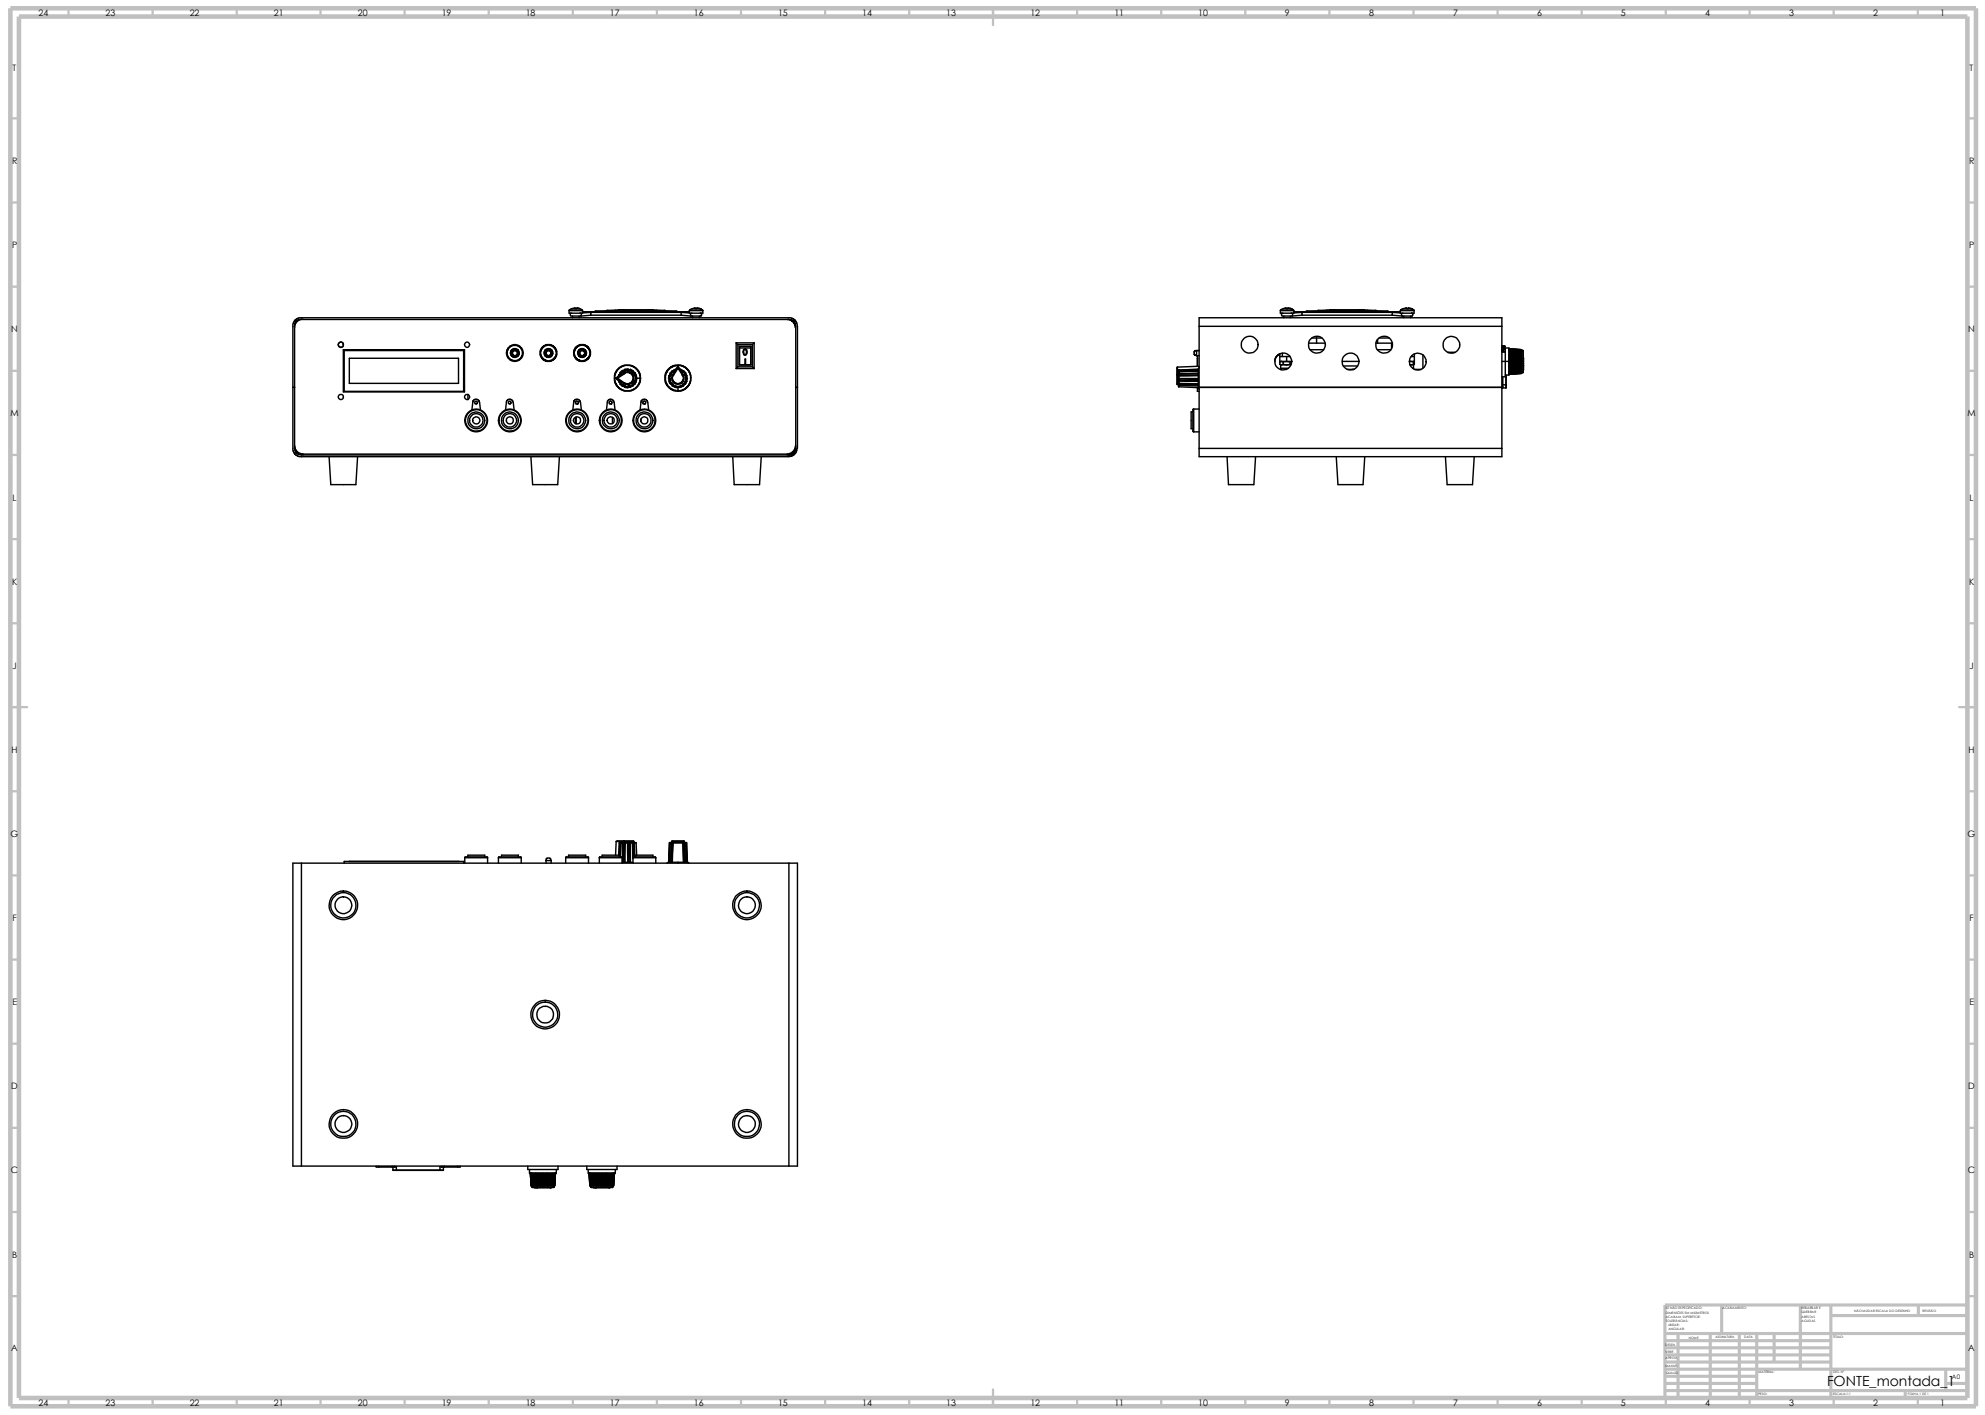
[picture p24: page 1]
NÃO MUDAR ESCALA DO DESENHO; REVISÃO; ACABAMENTO:; AGUDAS; REBARBAR E QUEBRAR ARESTAS

SE NÃO ESPECIFICADO:
DIMENSÕES EM MILÍMETROS
ACABAM. SUPERFÍCIE:
TOLERÂNCIAS:
LINEAR:
ANGULAR:

NOME | ASSINATURA | DATA | | | | TÍTULO:

DESEN.

VERIF.

APROV.

MANUF.
QUALID | | | | MATERIAL: | DES. Nº FONTE_montada_1 | A0

PESO: | ESCALA:1:1 FOLHA 1 DE 1

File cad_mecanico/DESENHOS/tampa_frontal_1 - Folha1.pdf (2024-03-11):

E | E
F | F

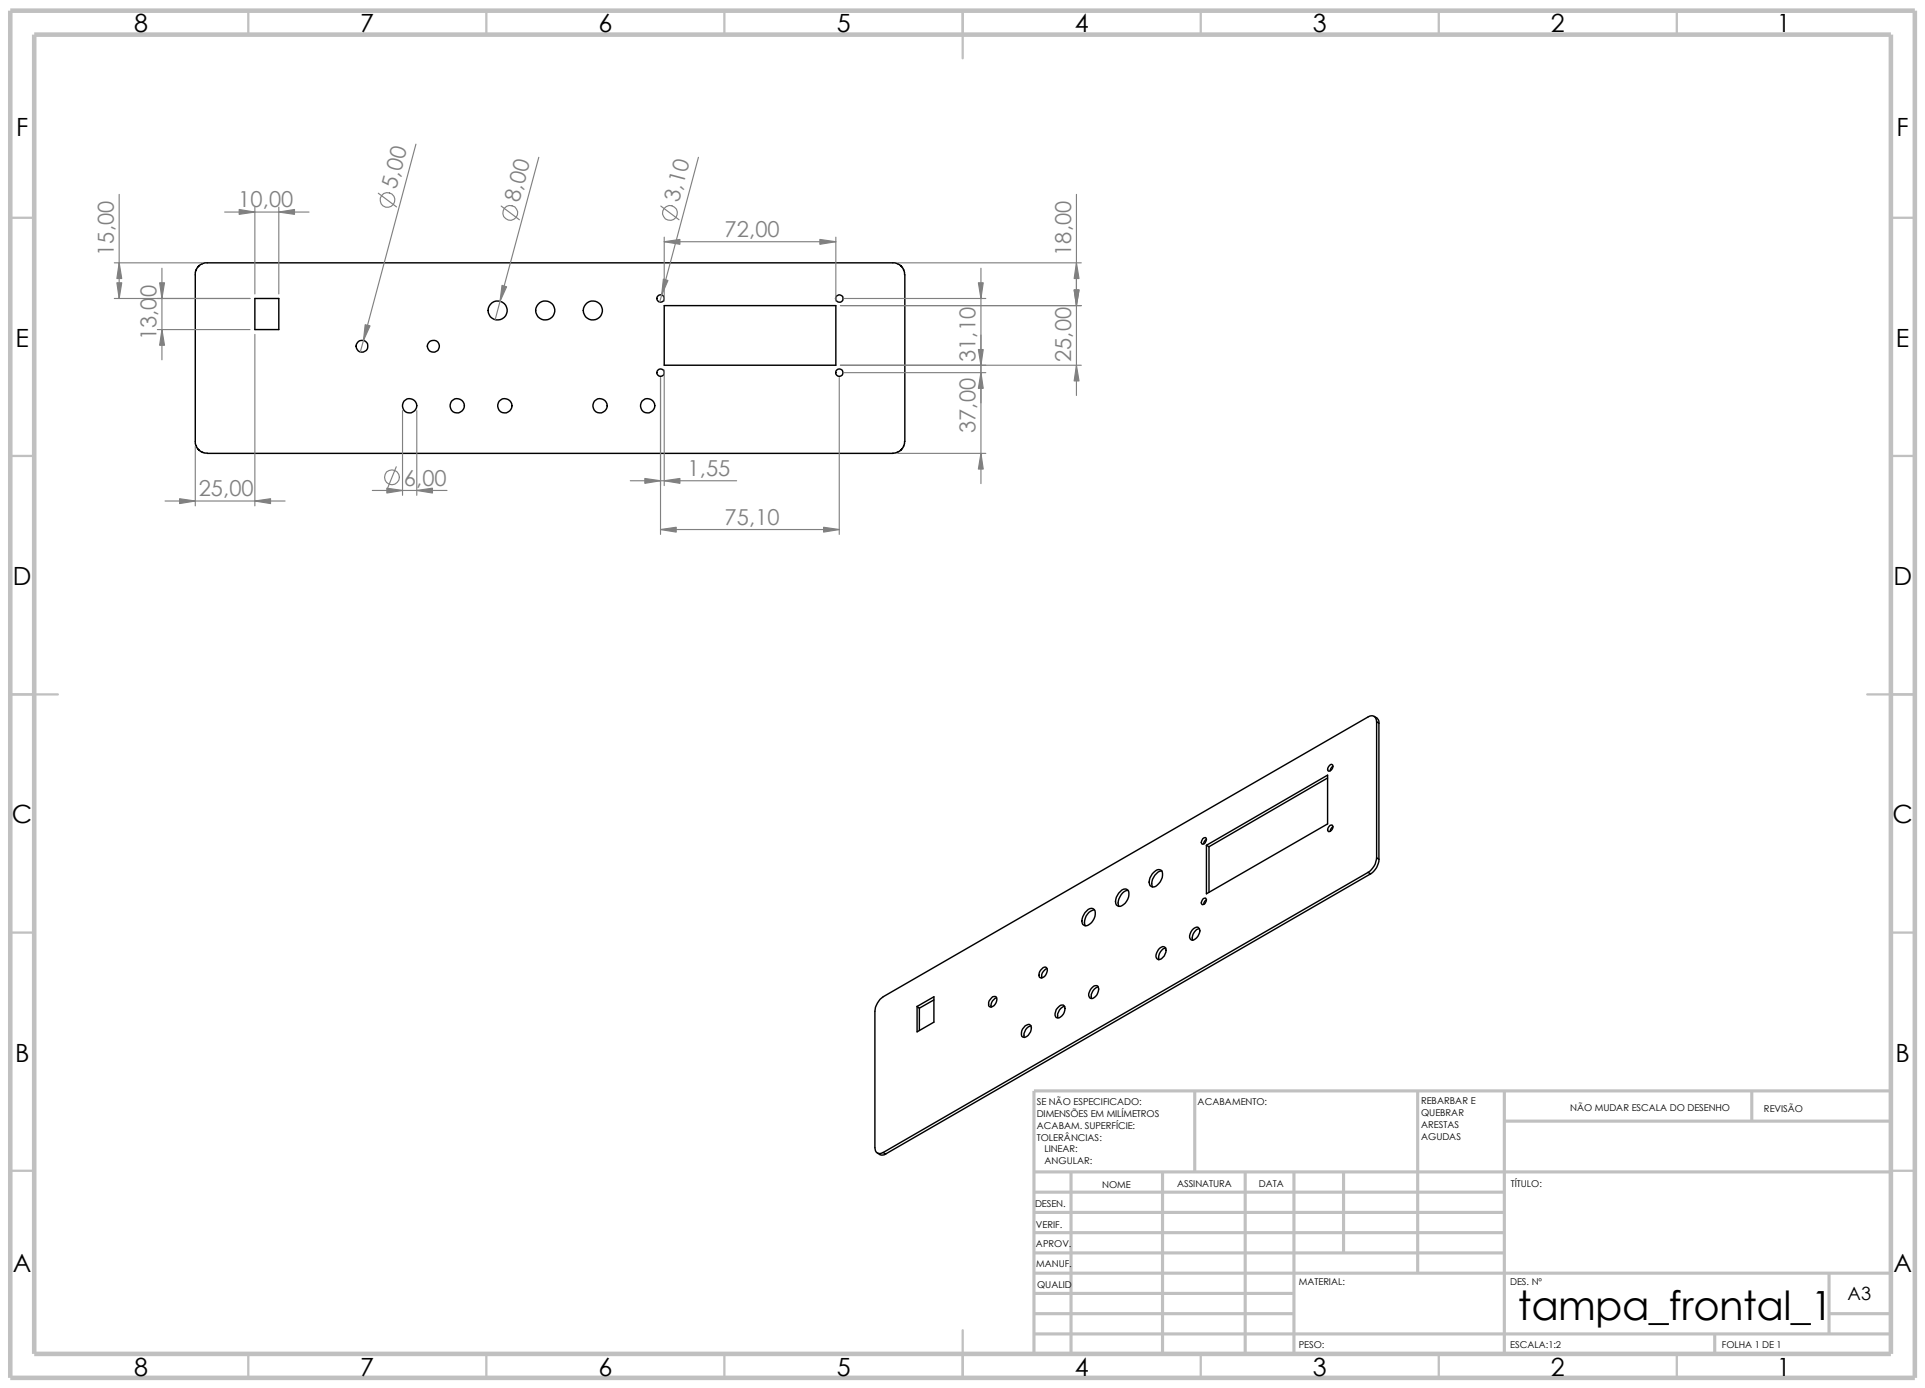
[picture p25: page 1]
NÃO MUDAR ESCALA DO DESENHO; REVISÃO; ESCALA:1:2; FOLHA 1 DE 1; PESO:; AGUDAS; SE NÃO ESPECIFICADO:; ACABAMENTO:; REBARBAR E QUEBRAR ARESTAS

DIMENSÕES EM MILÍMETROS
ACABAM. SUPERFÍCIE:
TOLERÂNCIAS:
LINEAR:
ANGULAR:

NOME | ASSINATURA | DATA | | | | TÍTULO:

DESEN.

VERIF.

APROV.

MANUF.
QUALID | | | | MATERIAL: | DES. Nº tampa_frontal_1 | A3

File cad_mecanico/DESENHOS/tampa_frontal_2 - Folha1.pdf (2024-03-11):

E | E
F | F

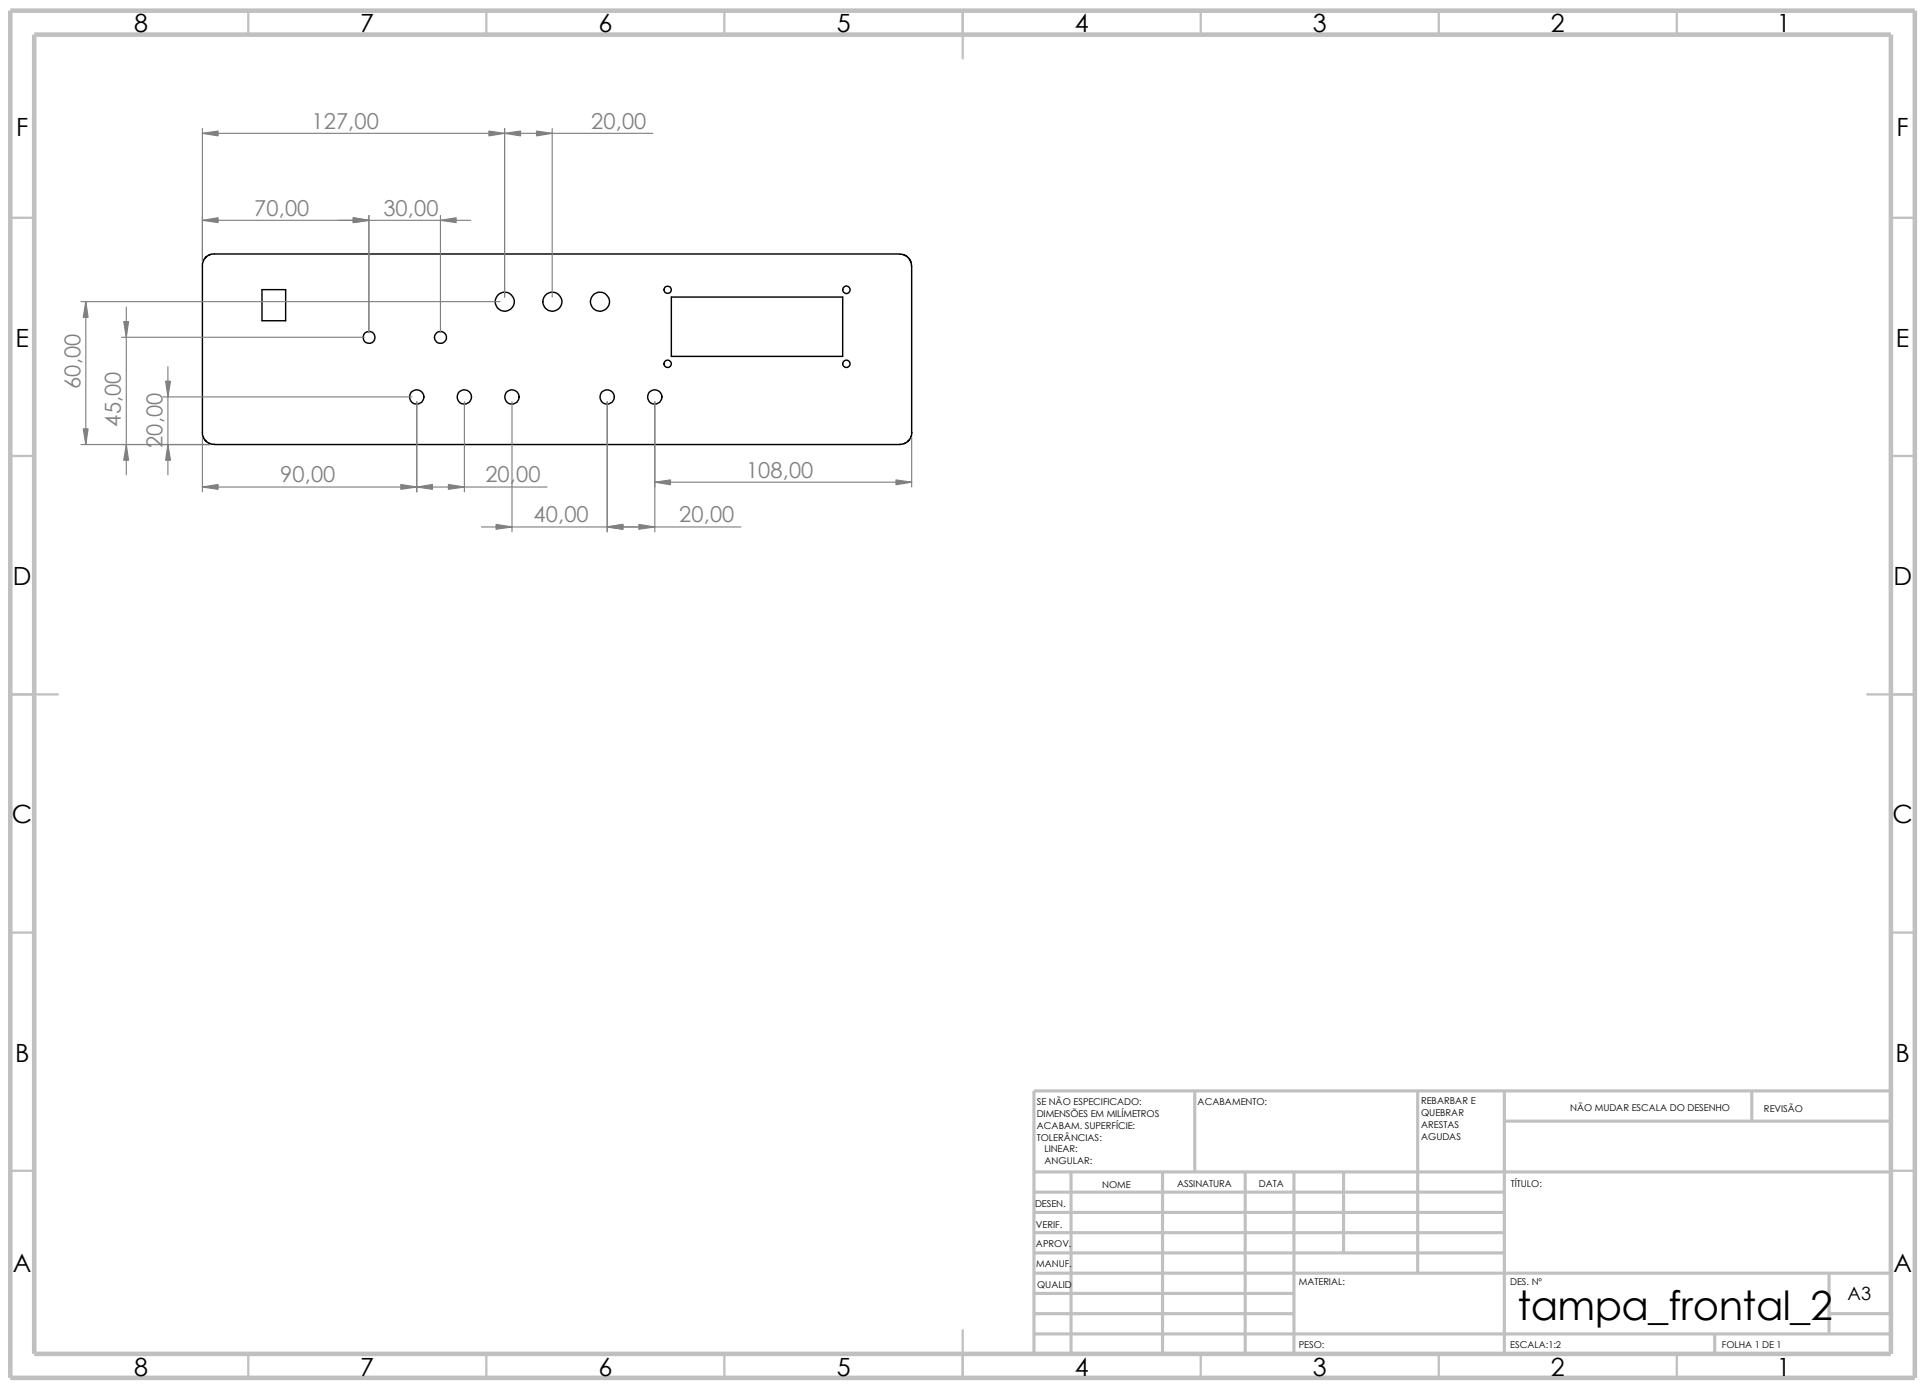
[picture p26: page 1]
FOLHA 1 DE 1; PESO:; ESCALA:1:2; NÃO MUDAR ESCALA DO DESENHO; REVISÃO; ACABAMENTO:; AGUDAS; REBARBAR E QUEBRAR ARESTAS

SE NÃO ESPECIFICADO:
DIMENSÕES EM MILÍMETROS
ACABAM. SUPERFÍCIE:
TOLERÂNCIAS:
LINEAR:
ANGULAR:

NOME | ASSINATURA | DATA | | | | TÍTULO:

DESEN.

VERIF.

APROV.

MANUF.
QUALID | | | | MATERIAL: | DES. Nº tampa_frontal_2 | A3

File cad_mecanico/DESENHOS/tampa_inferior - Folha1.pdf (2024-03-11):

E | E
F | F

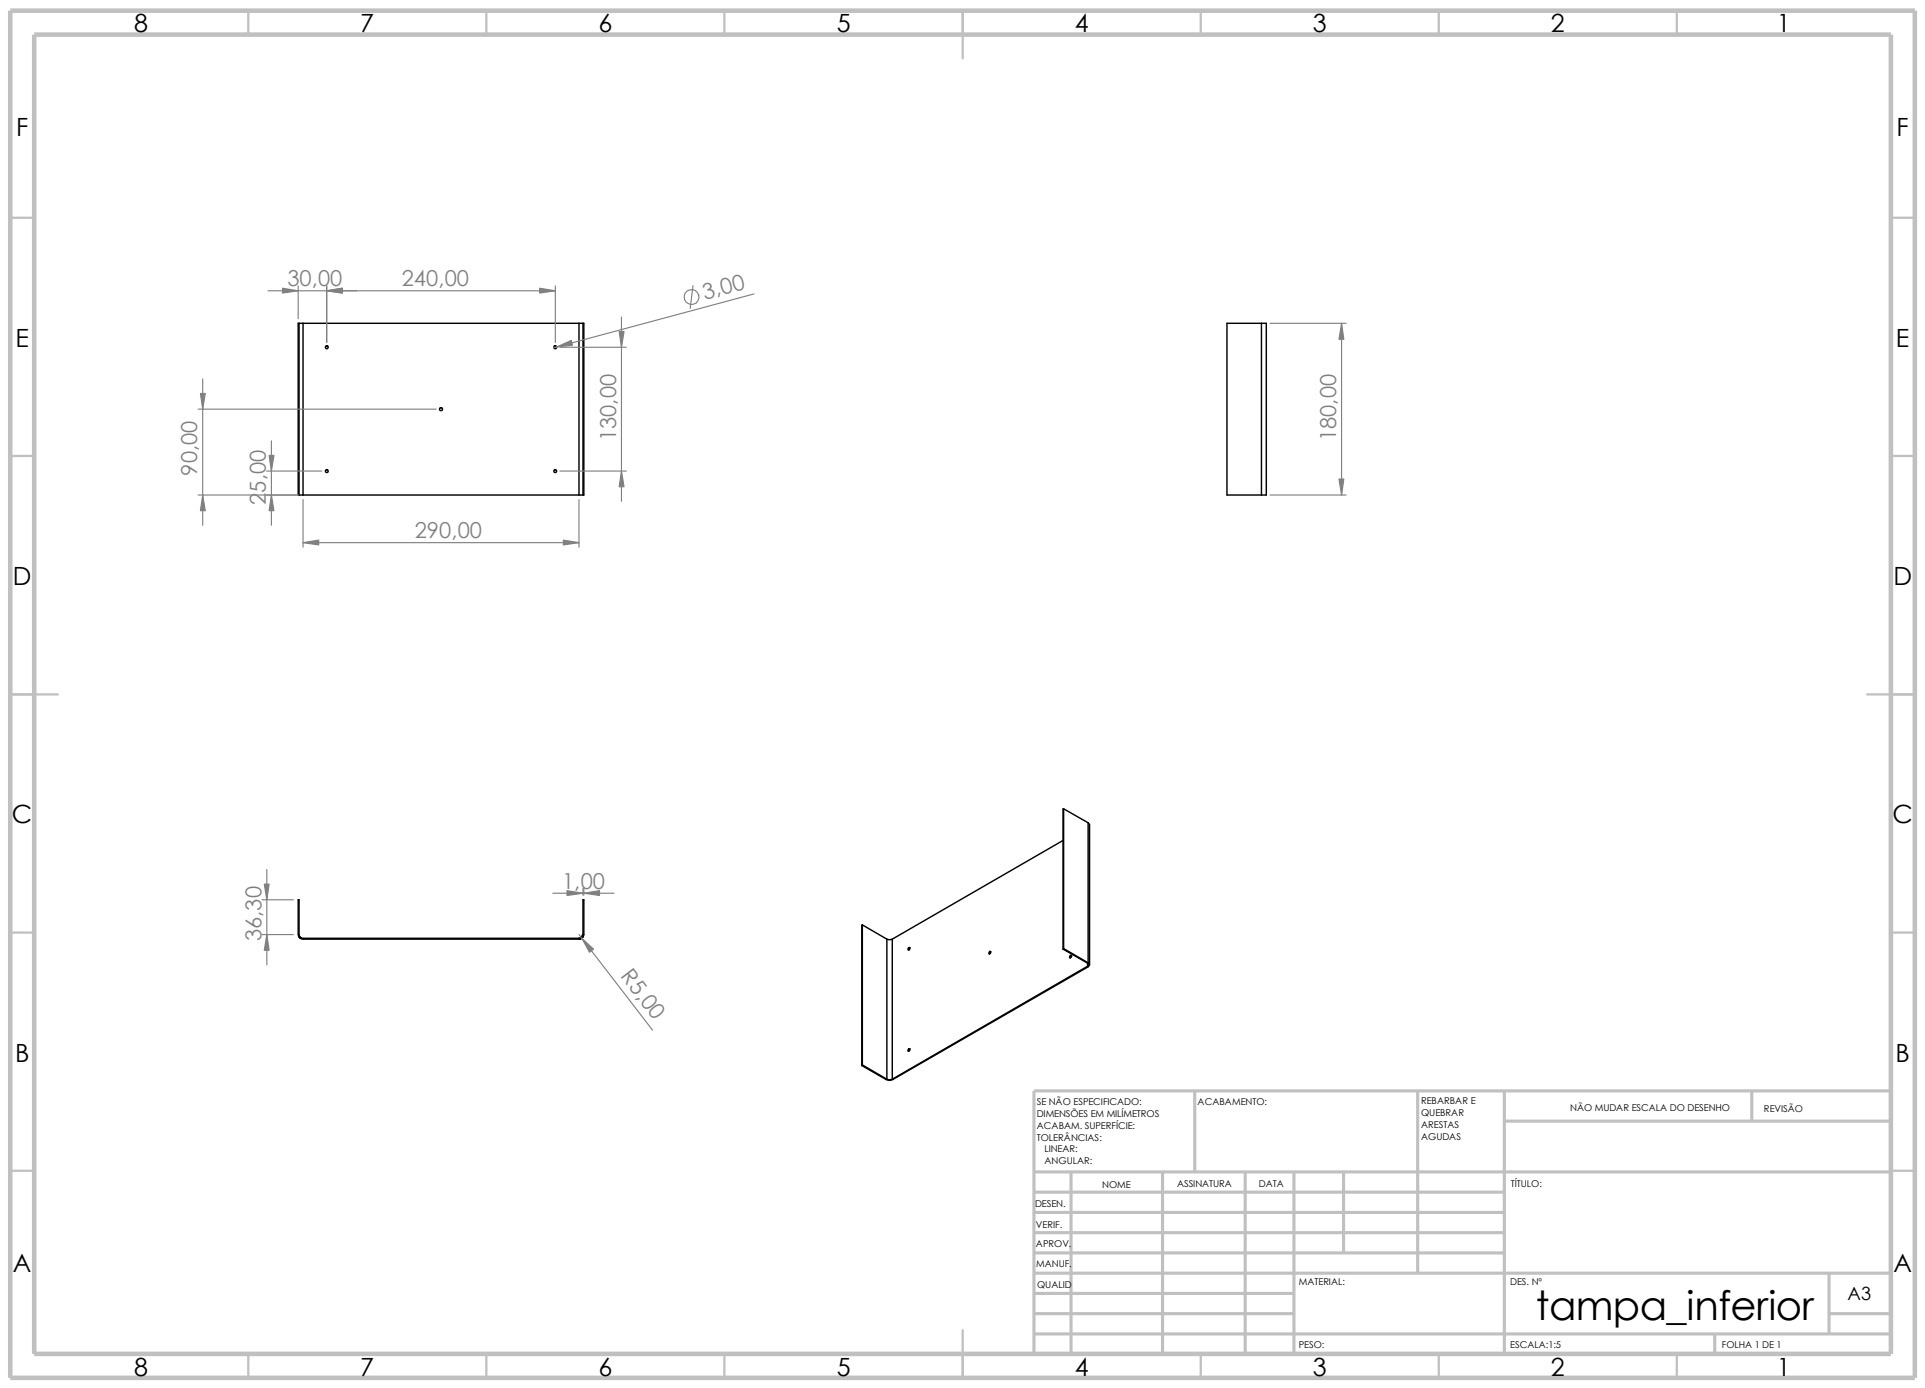
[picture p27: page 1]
ESCALA:1:5; FOLHA 1 DE 1; PESO:; NÃO MUDAR ESCALA DO DESENHO; REVISÃO; ACABAMENTO:; AGUDAS; REBARBAR E QUEBRAR ARESTAS

SE NÃO ESPECIFICADO:
DIMENSÕES EM MILÍMETROS
ACABAM. SUPERFÍCIE:
TOLERÂNCIAS:
LINEAR:
ANGULAR:

NOME | ASSINATURA | DATA | | | | TÍTULO:

DESEN.

VERIF.

APROV.

MANUF.
QUALID | | | | MATERIAL: | DES. Nº tampa_inferior | A3

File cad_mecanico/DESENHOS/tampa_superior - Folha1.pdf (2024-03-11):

E | E
F | F

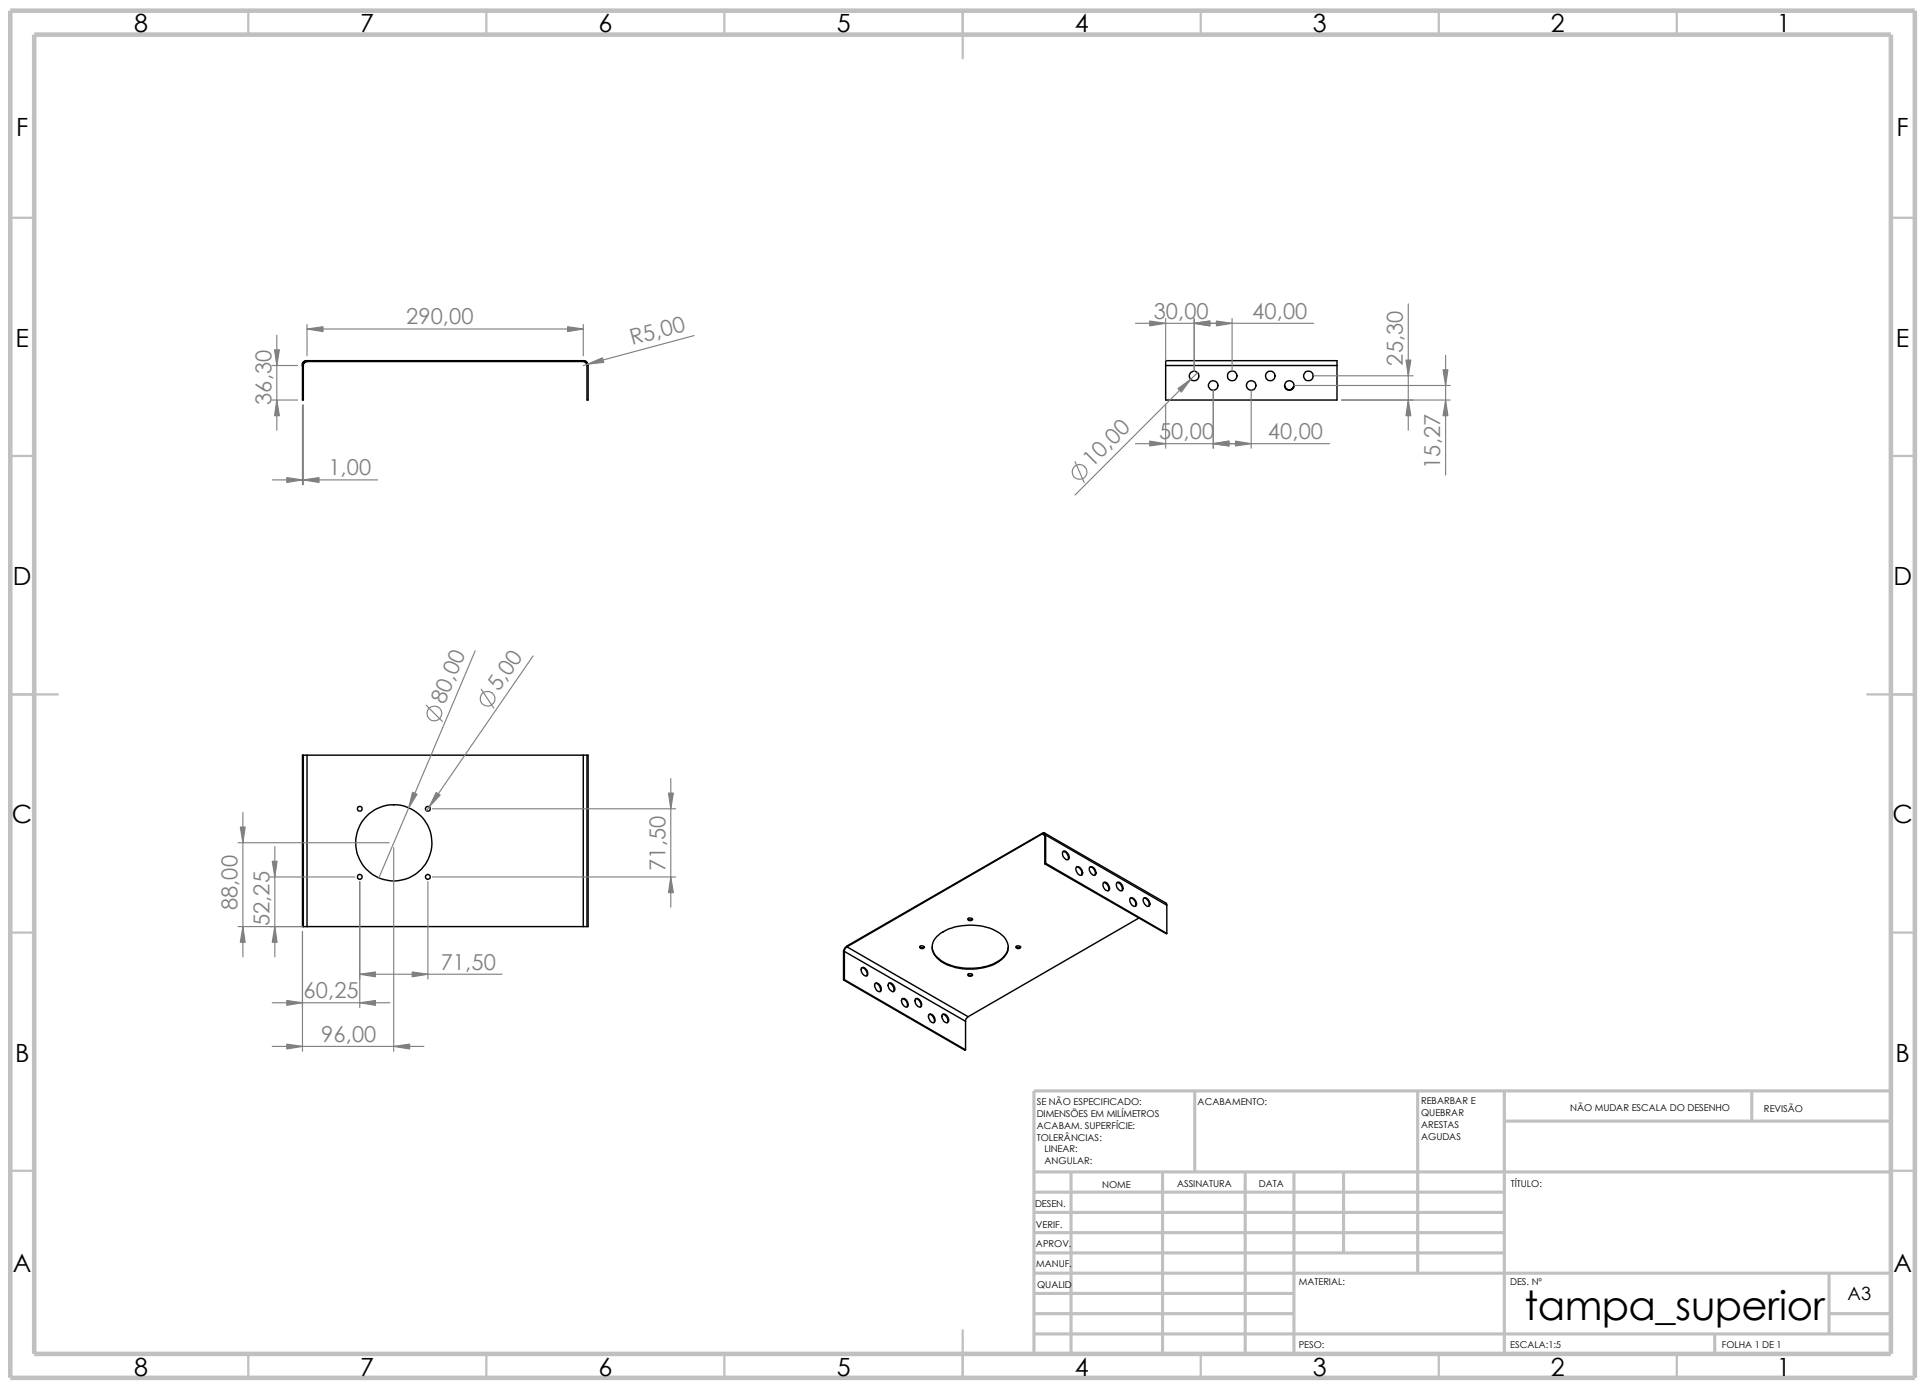
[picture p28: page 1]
FOLHA 1 DE 1; PESO:; ESCALA:1:5; NÃO MUDAR ESCALA DO DESENHO; REVISÃO; ACABAMENTO:; AGUDAS; REBARBAR E QUEBRAR ARESTAS

SE NÃO ESPECIFICADO:
DIMENSÕES EM MILÍMETROS
ACABAM. SUPERFÍCIE:
TOLERÂNCIAS:
LINEAR:
ANGULAR:

NOME | ASSINATURA | DATA | | | | TÍTULO:

DESEN.

VERIF.

APROV.

MANUF.
QUALID | | | | MATERIAL: | DES. Nº tampa_superior | A3

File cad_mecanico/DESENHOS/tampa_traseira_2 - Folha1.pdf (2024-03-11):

E | E
F | F

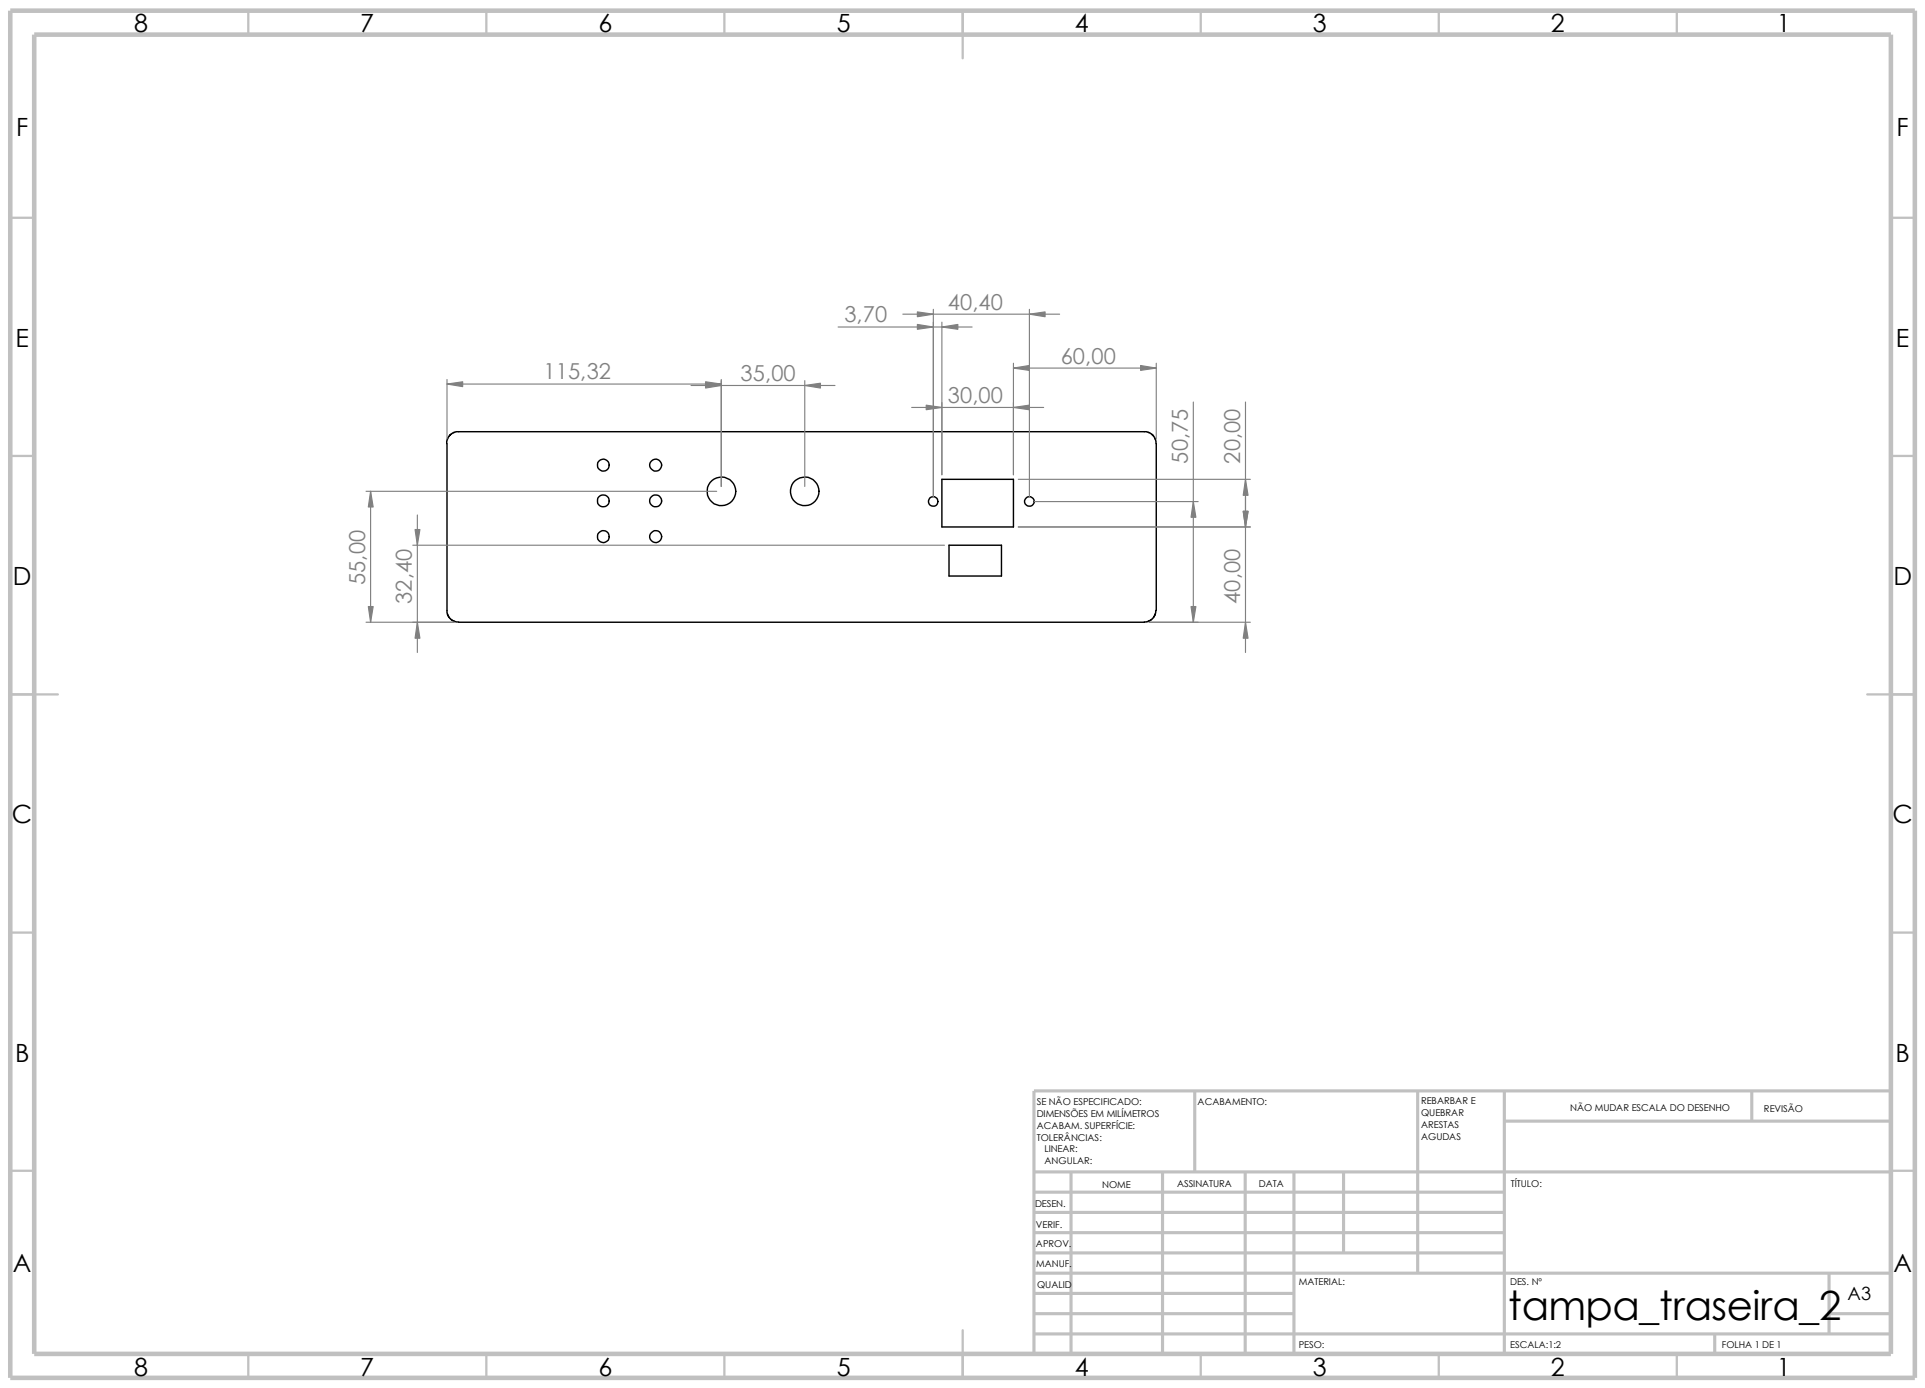
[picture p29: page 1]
PESO:; ESCALA:1:2; FOLHA 1 DE 1; REVISÃO; ACABAMENTO:; AGUDAS; REBARBAR E QUEBRAR ARESTAS

NÃO MUDAR ESCALA DO DESENHO SE NÃO ESPECIFICADO:
DIMENSÕES EM MILÍMETROS
ACABAM. SUPERFÍCIE:
TOLERÂNCIAS:
LINEAR:
ANGULAR:

NOME | ASSINATURA | DATA | | | | TÍTULO:

DESEN.

VERIF.

APROV.

MANUF.
QUALID | | | | MATERIAL: | DES. Nº tampa_traseira_2 | A3

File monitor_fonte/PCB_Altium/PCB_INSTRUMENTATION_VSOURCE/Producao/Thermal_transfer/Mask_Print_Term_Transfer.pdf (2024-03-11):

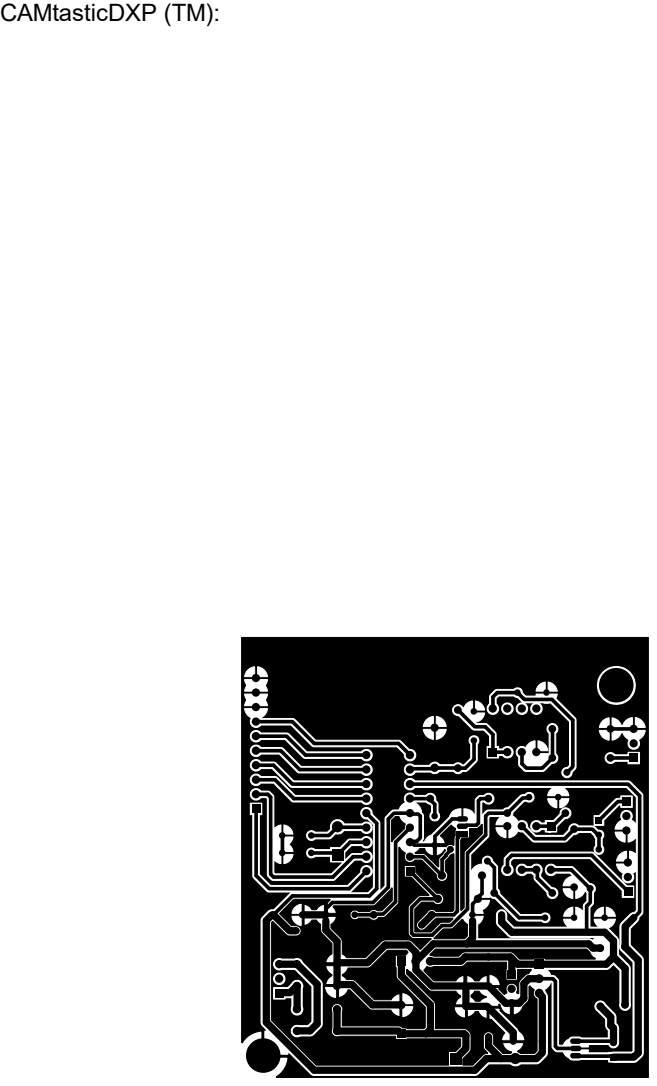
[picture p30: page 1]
CAMtasticDXP (TM):

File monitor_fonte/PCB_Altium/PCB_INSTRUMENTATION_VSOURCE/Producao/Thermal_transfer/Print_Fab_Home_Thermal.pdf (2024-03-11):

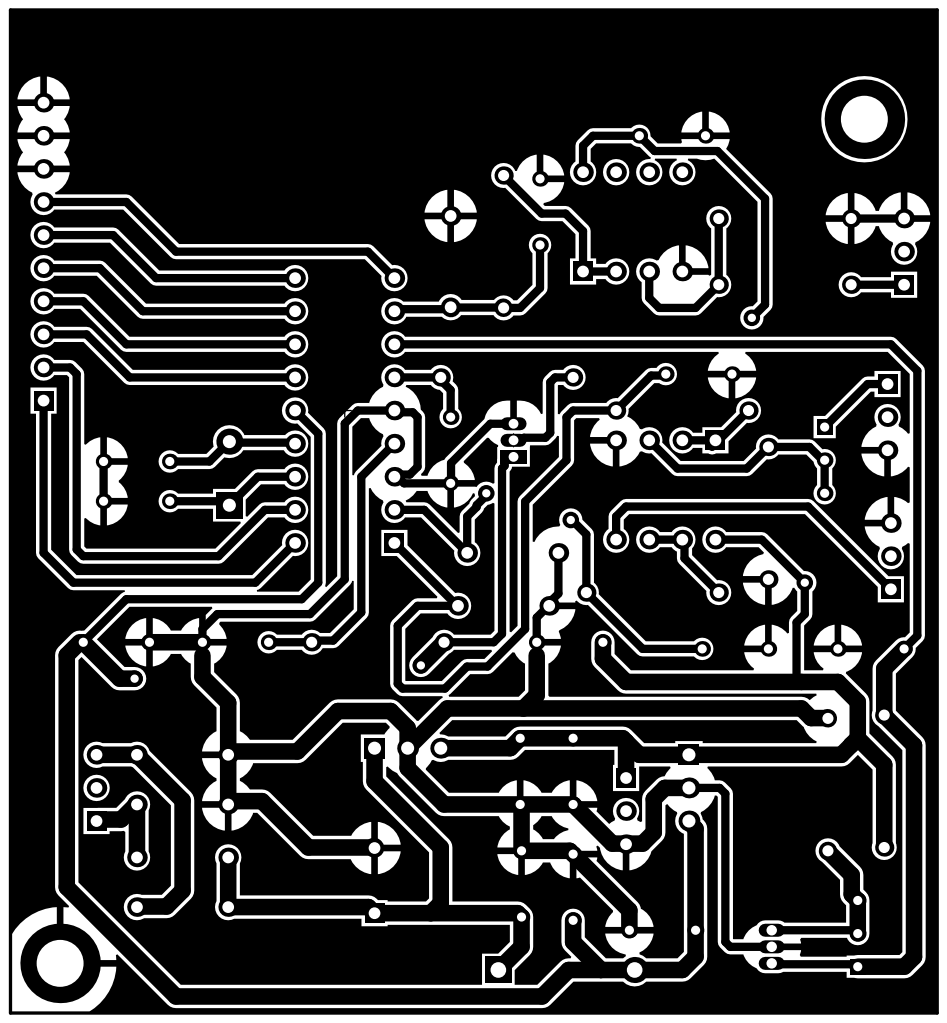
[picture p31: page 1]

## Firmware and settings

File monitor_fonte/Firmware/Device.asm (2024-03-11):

_Device_init:

;Device.c,64 :: 		Device_init(){
;Device.c,66 :: 		Device_GPIO_init();
	CALL        _Device_GPIO_init+0, 0
;Device.c,68 :: 		Device_ADC_init();
	CALL        _Device_ADC_init+0, 0
;Device.c,70 :: 		Device_display_init();
	CALL        _Device_display_init+0, 0
;Device.c,74 :: 		Delay_ms(1000);
	MOVLW       13
	MOVWF       R11, 0
	MOVLW       175
	MOVWF       R12, 0
	MOVLW       182
	MOVWF       R13, 0
L_Device_init0:
	DECFSZ      R13, 1, 1
	BRA         L_Device_init0
	DECFSZ      R12, 1, 1
	BRA         L_Device_init0
	DECFSZ      R11, 1, 1
	BRA         L_Device_init0
	NOP
;Device.c,75 :: 		Lcd_Cmd(_LCD_CLEAR);            // Clear display
	MOVLW       1
	MOVWF       FARG_Lcd_Cmd_out_char+0 
	CALL        _Lcd_Cmd+0, 0
;Device.c,76 :: 		}
L_end_Device_init:
	RETURN      0
; end of _Device_init

_Device_GPIO_init:

;Device.c,78 :: 		Device_GPIO_init(){
;Device.c,81 :: 		TRISA = 0x0F;
	MOVLW       15
	MOVWF       TRISA+0 
;Device.c,83 :: 		TRISB = 0x01;
	MOVLW       1
	MOVWF       TRISB+0 
;Device.c,85 :: 		PORTA = 0x00;
	CLRF        PORTA+0 
;Device.c,86 :: 		PORTB = 0x00;
	CLRF        PORTB+0 
;Device.c,87 :: 		}
L_end_Device_GPIO_init:
	RETURN      0
; end of _Device_GPIO_init

_Device_ADC_init:

;Device.c,89 :: 		Device_ADC_init(){
;Device.c,94 :: 		ADCON1  = 0x60;;
	MOVLW       96
	MOVWF       ADCON1+0 
;Device.c,96 :: 		ADCON0  = 0x41;;
	MOVLW       65
	MOVWF       ADCON0+0 
;Device.c,98 :: 		ADCON2  = 0x88;
	MOVLW       136
	MOVWF       ADCON2+0 
;Device.c,99 :: 		}
L_end_Device_ADC_init:
	RETURN      0
; end of _Device_ADC_init

_Device_display_init:

;Device.c,116 :: 		Device_display_init(){
;Device.c,117 :: 		Lcd_Init();                     // Initialize LCD
	CALL        _Lcd_Init+0, 0
;Device.c,118 :: 		Lcd_Cmd(_LCD_CLEAR);            // Clear display
	MOVLW       1
	MOVWF       FARG_Lcd_Cmd_out_char+0 
	CALL        _Lcd_Cmd+0, 0
;Device.c,119 :: 		Lcd_Cmd(_LCD_CURSOR_OFF);       // Cursor off
	MOVLW       12
	MOVWF       FARG_Lcd_Cmd_out_char+0 
	CALL        _Lcd_Cmd+0, 0
;Device.c,120 :: 		Lcd_Out(1,3,"INITIALIZING");
	MOVLW       1
	MOVWF       FARG_Lcd_Out_row+0 
	MOVLW       3
	MOVWF       FARG_Lcd_Out_column+0 
	MOVLW       ?lstr1_Device+0
	MOVWF       FARG_Lcd_Out_text+0 
	MOVLW       hi_addr(?lstr1_Device+0)
	MOVWF       FARG_Lcd_Out_text+1 
	CALL        _Lcd_Out+0, 0
;Device.c,121 :: 		}
L_end_Device_display_init:
	RETURN      0
; end of _Device_display_init

_Device_run:

;Device.c,123 :: 		Device_run(){
;Device.c,130 :: 		Delay_ms(LOOP_DELAY);
	MOVLW       11
	MOVWF       R11, 0
	MOVLW       38
	MOVWF       R12, 0
	MOVLW       93
	MOVWF       R13, 0
L_Device_run1:
	DECFSZ      R13, 1, 1
	BRA         L_Device_run1
	DECFSZ      R12, 1, 1
	BRA         L_Device_run1
	DECFSZ      R11, 1, 1
	BRA         L_Device_run1
	NOP
	NOP
;Device.c,131 :: 		PORTB.RB7 = ~PORTB.RB7;  //heartbeat
	BTG         PORTB+0, 7 
;Device.c,133 :: 		voltageVar  = Device_meseure_average(CHANNEL0);
	CLRF        FARG_Device_meseure_average_channel+0 
	CALL        _Device_meseure_average+0, 0
	MOVF        R0, 0 
	MOVWF       Device_run_voltageVar_L0+0 
	MOVF        R1, 0 
	MOVWF       Device_run_voltageVar_L0+1 
;Device.c,134 :: 		voltageVar  = voltageVar * V_MAX ; // Vmax source to 35V  (35000/1023)
	CALL        _word2double+0, 0
	MOVLW       226
	MOVWF       R4 
	MOVLW       105
	MOVWF       R5 
	MOVLW       15
	MOVWF       R6 
	MOVLW       132
	MOVWF       R7 
	CALL        _Mul_32x32_FP+0, 0
	CALL        _double2word+0, 0
	MOVF        R0, 0 
	MOVWF       Device_run_voltageVar_L0+0 
	MOVF        R1, 0 
	MOVWF       Device_run_voltageVar_L0+1 
;Device.c,135 :: 		Device_print_voltage_measure(voltageVar);
	MOVF        R0, 0 
	MOVWF       FARG_Device_print_voltage_measure_voltage+0 
	MOVF        R1, 0 
	MOVWF       FARG_Device_print_voltage_measure_voltage+1 
	CALL        _Device_print_voltage_measure+0, 0
;Device.c,137 :: 		voltageFix = Device_meseure_average(CHANNEL4);
	MOVLW       4
	MOVWF       FARG_Device_meseure_average_channel+0 
	CALL        _Device_meseure_average+0, 0
;Device.c,138 :: 		voltageFix = voltageFix * B_2_V; // To 5V   (5000/1023)
	CALL        _word2double+0, 0
	MOVLW       56
	MOVWF       R4 
	MOVLW       103
	MOVWF       R5 
	MOVLW       28
	MOVWF       R6 
	MOVLW       129
	MOVWF       R7 
	CALL        _Mul_32x32_FP+0, 0
	CALL        _double2word+0, 0
;Device.c,139 :: 		Device_print_voltage_fixed_measure(voltageFix);
	MOVF        R0, 0 
	MOVWF       FARG_Device_print_voltage_fixed_measure_voltage+0 
	MOVF        R1, 0 
	MOVWF       FARG_Device_print_voltage_fixed_measure_voltage+1 
	CALL        _Device_print_voltage_fixed_measure+0, 0
;Device.c,141 :: 		currentVar  = Device_meseure_average(CHANNEL1);
	MOVLW       1
	MOVWF       FARG_Device_meseure_average_channel+0 
	CALL        _Device_meseure_average+0, 0
	MOVF        R0, 0 
	MOVWF       Device_run_currentVar_L0+0 
	MOVF        R1, 0 
	MOVWF       Device_run_currentVar_L0+1 
;Device.c,147 :: 		if(currentVar < offset){
	MOVLW       2
	SUBWF       R1, 0 
	BTFSS       STATUS+0, 2 
	GOTO        L__Device_run38
	MOVLW       0
	SUBWF       R0, 0 
L__Device_run38:
	BTFSC       STATUS+0, 0 
	GOTO        L_Device_run2
;Device.c,148 :: 		currentVar = offset;
	MOVLW       0
	MOVWF       Device_run_currentVar_L0+0 
	MOVLW       2
	MOVWF       Device_run_currentVar_L0+1 
;Device.c,149 :: 		}else{
	GOTO        L_Device_run3
L_Device_run2:
;Device.c,150 :: 		currentVar = (currentVar - offset);
	MOVLW       0
	SUBWF       Device_run_currentVar_L0+0, 1 
	MOVLW       2
	SUBWFB      Device_run_currentVar_L0+1, 1 
;Device.c,151 :: 		}
L_Device_run3:
;Device.c,153 :: 		currentVar = currentVar * B_2_V; //To 5V   (5000/1023) / 185 mV/A= I
	MOVF        Device_run_currentVar_L0+0, 0 
	MOVWF       R0 
	MOVF        Device_run_currentVar_L0+1, 0 
	MOVWF       R1 
	CALL        _word2double+0, 0
	MOVLW       56
	MOVWF       R4 
	MOVLW       103
	MOVWF       R5 
	MOVLW       28
	MOVWF       R6 
	MOVLW       129
	MOVWF       R7 
	CALL        _Mul_32x32_FP+0, 0
	CALL        _double2word+0, 0
	MOVF        R0, 0 
	MOVWF       Device_run_currentVar_L0+0 
	MOVF        R1, 0 
	MOVWF       Device_run_currentVar_L0+1 
;Device.c,154 :: 		currentVar = currentVar/SENS_CUR;
	CALL        _word2double+0, 0
	MOVLW       164
	MOVWF       R4 
	MOVLW       112
	MOVWF       R5 
	MOVLW       61
	MOVWF       R6 
	MOVLW       124
	MOVWF       R7 
	CALL        _Div_32x32_FP+0, 0
	CALL        _double2word+0, 0
	MOVF        R0, 0 
	MOVWF       Device_run_currentVar_L0+0 
	MOVF        R1, 0 
	MOVWF       Device_run_currentVar_L0+1 
;Device.c,157 :: 		Device_print_current_measure(currentVar);
	MOVF        R0, 0 
	MOVWF       FARG_Device_print_current_measure_current+0 
	MOVF        R1, 0 
	MOVWF       FARG_Device_print_current_measure_current+1 
	CALL        _Device_print_current_measure+0, 0
;Device.c,159 :: 		powerVar = (voltageVar/1000) * (currentVar/10);// rearranje numbers
	MOVLW       232
	MOVWF       R4 
	MOVLW       3
	MOVWF       R5
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

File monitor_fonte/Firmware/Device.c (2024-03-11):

/****************************************************************
* @file : Device.c
*
*
*****************************************************************/

/*includes */
#include "Device.h"

/* Macros */
#define V_MAX  (35.8534)  // Calibration (36678/1023)
#define B_2_V   (4.8876)  // To 5V convertion bits to volts (5000/1023)
#define SENS_CUR (0.185)  // To 5V (5000/1023) / 0.185 mV/A= I
#define LOOP_DELAY (800)  // Delay for infinite loop
#define N_AVAREGE  (12U)  // Number of average

/* Global Variables */

// LCD module connections
sbit LCD_RS at RB4_bit;
sbit LCD_EN at RB5_bit;
sbit LCD_D4 at RB6_bit;
sbit LCD_D5 at RB1_bit;
sbit LCD_D6 at RB2_bit;
sbit LCD_D7 at RB3_bit;

sbit LCD_RS_Direction at TRISB4_bit;
sbit LCD_EN_Direction at TRISB5_bit;
sbit LCD_D4_Direction at TRISB0_bit;
sbit LCD_D5_Direction at TRISB1_bit;
sbit LCD_D6_Direction at TRISB2_bit;
sbit LCD_D7_Direction at TRISB3_bit;
// End LCD module connections

const int  offset = 512;

/*
unsigned int timer_counter;

 void interrupt()
{
   if(TMR0IF_bit){
      timer_counter++;
      TMR0L = 0;     //1ms
      TMR0H = 251;
      TMR0IF_bit = 0x00;
      //RB7_bit = ~RB7_bit;
      //Device_run();
   }

}*/

/*Functions prototipe */
Device_display_init();
Device_GPIO_init();
Device_ADC_init();
//Device_TIMER_init();

/*Implementation */

Device_init(){

  Device_GPIO_init();
  
  Device_ADC_init();
  
  Device_display_init();
  
  //Device_TIMER_init();
  
  Delay_ms(1000);
  Lcd_Cmd(_LCD_CLEAR);            // Clear display
}

Device_GPIO_init(){
  /*IO pins configuration*/
  /*PA 0,1,2,3 = In, 4,5,6,7 = Out*/
  TRISA = 0x0F;
  /*PB 0 = In, 1,2,3,4,5,6,7 = Out*/
  TRISB = 0x01;
  /*Ports initialize*/
  PORTA = 0x00;
  PORTB = 0x00;
}

Device_ADC_init(){
  /*Configure AN6,5 as digital, AN 4,3,2,1,0 as
  * analog channel and AN 3 as Vref+ external
  * AN4 = VF, AN2 = Temp, AN1 = current, AN0 = Voltage
  */
  ADCON1  = 0x60;;
  /*AN module ON  */
  ADCON0  = 0x41;;
  /* Right justified, Aq time = 2TAD, AD clock = Fosc/2*/
  ADCON2  = 0x88;
}

//Device_TIMER_init(){
  /* Machine Cycle = (10Mhz/4 = 2.5 MHz), T = 1/2.5MHz = 400ns
  *T0-> 16 bits, PS = 2, T0 time = ((65535-1250) x 400ns x 2 = 1ms
  *TMR0L + TMR0H = 64285 -> TMROL = 0 / TMR0H = 251 (64285/256)*/
//  T0CON = 0x080; // 100us
  /*Enable global interrupt, periferal, TMR0 overflow*/
//  GIE_bit = 0x01;
//  PEIE_bit = 0x01;
//  TMR0IE_bit = 0x01;
  /* Start timer0 counter with 206  = 50 x 400ns = 20us*/
//  TMR0L = 0;     //1ms
//  TMR0H = 251;
//}


Device_display_init(){
  Lcd_Init();                     // Initialize LCD
  Lcd_Cmd(_LCD_CLEAR);            // Clear display
  Lcd_Cmd(_LCD_CURSOR_OFF);       // Cursor off
  Lcd_Out(1,3,"INITIALIZING");
}

Device_run(){
      unsigned int voltageVar, voltageFix, currentVar,temperatureVar, powerVar;

      /*if(timer_counter == 1000){
         PORTB.RB7 = ~PORTB.RB7;  //heartbeat
         timer_counter = 0x00;
      }*/
      Delay_ms(LOOP_DELAY);
      PORTB.RB7 = ~PORTB.RB7;  //heartbeat
      
      voltageVar  = Device_meseure_average(CHANNEL0);
      voltageVar  = voltageVar * V_MAX ; // Vmax source to 35V  (35000/1023)
      Device_print_voltage_measure(voltageVar);

      voltageFix = Device_meseure_average(CHANNEL4);
      voltageFix = voltageFix * B_2_V; // To 5V   (5000/1023)
      Device_print_voltage_fixed_measure(voltageFix);

      currentVar  = Device_meseure_average(CHANNEL1);
      if(currentVar < offset){
          currentVar = offset;
      }else{
         currentVar = (currentVar - offset);
      }
      currentVar = currentVar * B_2_V; //To 5V   (5000/1023) / 185 mV/A= I
      currentVar = currentVar/SENS_CUR;
      Device_print_current_measure(currentVar);

      powerVar = (voltageVar/1000) * (currentVar/10);// rearranje numbers
      Device_print_power_measure(powerVar);

      temperatureVar  = Device_meseure_average(CHANNEL2);
      temperatureVar = temperatureVar * B_2_V; //voltage in miliVolts
      Device_print_temperature_measure(temperatureVar);

}

Device_print_voltage_measure(unsigned int voltage){
    char dez_milhar, milhar, cent, dez, uni;
    /* convertion numbers to display */
    dez_milhar = (voltage/10000);
    milhar =  (voltage%10000)/1000;
    cent =    (voltage%1000)/100;
    dez =     (voltage%100)/10;
    uni =     (voltage%10);
    
    Lcd_Chr(1,1,'V');
    Lcd_Chr_Cp('=');
    Lcd_Chr_Cp(dez_milhar + 0x30);  // (0x30 offset ASCII charracters)
    Lcd_Chr_Cp(milhar + 0x30);
    Lcd_Chr_Cp('.');
    Lcd_Chr_Cp(cent+ 0x30);
    Lcd_Chr_Cp(dez + 0x30);
}

Device_print_voltage_fixed_measure(unsigned int voltage){

    Lcd_Chr(1,15,'V');
    Lcd_Chr_Cp('F');
    if(voltage < 1500){
       Lcd_Chr(2,15,'D');
       Lcd_Chr_Cp('N');
    }else if(voltage > 3000){
       Lcd_Chr(2,15,'U');
       Lcd_Chr_Cp('P');
    }else{
       Lcd_Chr(2,15,'O');
       Lcd_Chr_Cp('K');
    }
}

Device_print_current_measure(unsigned int current){
    char milhar, cent, dez, uni;

    milhar =  (current/1000);
    cent =    (current%1000)/100;
    dez =     (current%100)/10;
    uni =     (current%10);

    Lcd_Chr(2,1,'A');
    Lcd_Chr_Cp('=');
    Lcd_Chr_Cp(milhar + 0x30);
    Lcd_Chr_Cp('.');
    Lcd_Chr_Cp(cent+ 0x30);
    Lcd_Chr_Cp(dez + 0x30);
}

Device_print_power_measure(unsigned int power){

    char milhar, cent, dez;

    milhar =  (power/1000);
    cent =    (power%1000)/100;
    dez =     (power%100)/10;

    Lcd_Chr(2,8,'W');
    Lcd_Chr_Cp('=');
    Lcd_Chr_Cp(milhar + 0x30);
    Lcd_Chr_Cp(cent+ 0x30);
    Lcd_Chr_Cp('.');
    Lcd_Chr_Cp(dez + 0x30);

}

Device_print_temperature_measure(unsigned int voltage){
    char milhar, cent, dez;

    milhar =  (voltage/1000);
    cent =    (voltage%1000)/100;
    dez =     (voltage%100)/10;

    Lcd_Chr(1,9,'T');
    Lcd_Chr_Cp('=');
    Lcd_Chr_Cp(milhar + 0x30);
    Lcd_Chr_Cp(cent+ 0x30);
    Lcd_Chr_Cp(dez + 0x30);
}
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
